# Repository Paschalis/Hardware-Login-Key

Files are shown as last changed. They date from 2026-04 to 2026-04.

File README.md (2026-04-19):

# 🔐 Hardware Login Key

<p align="center">
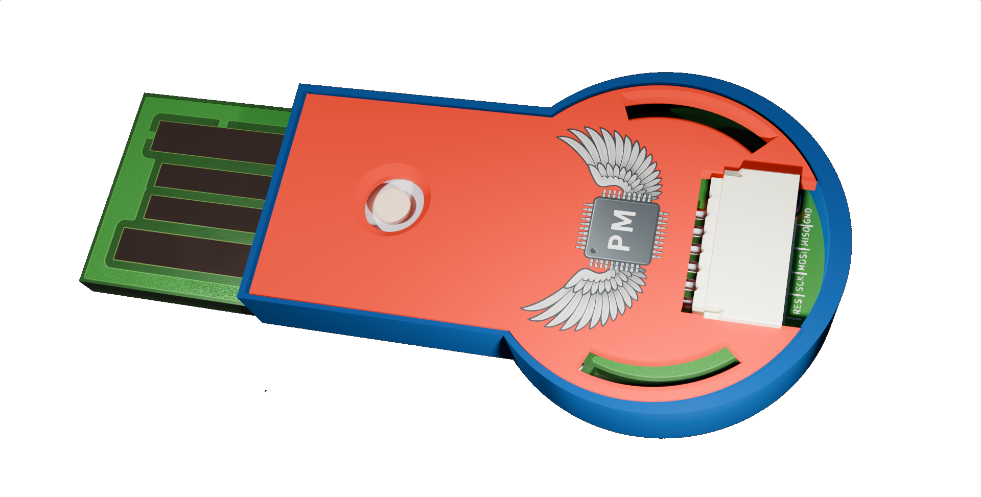
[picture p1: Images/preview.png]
Hardware Login Key preview
  <br/>

  
  
  
  
  
  
</p>

<p align="center">
  <b>Press or tap to auto-type your password suffix — the full password never exists in one place.</b><br/>
  <sub><i>The prefix stays in your mind, the suffix lives in your hand.</i></sub>
</p>

## Introduction

This project offers a straightforward solution for reducing password exposure when logging into a system or website. By pressing a physical button (or touching a capacitive pad) connected to an ATtiny85 microcontroller, the device automatically types a pre-stored password suffix, completing the login without exposing the full credential to observers.


<p align="center">
Pressing the tactile switch on the breadboard prototype sends a keystroke that appears in the terminal.
</p>

## 🎯 Purpose

The aim is to provide a practical alternative to manually typing long or complex passwords in environments where shoulder surfing or observation is a risk. The key injects only a suffix. The prefix stays in the user's memory, so physical possession of the device alone is not enough to authenticate.

## Benefits

- **Reduced exposure** — the full password is never typed in one place or stored in one location
- **Convenience** — complex suffixes are entered automatically with a button press
- **Privacy** — reduces shoulder surfing risk in public or shared environments
- **Portability** — a USB key fits on a keyring and works on any host

## ⚠️ Security Model & Limitations

This device is a **convenience tool**, not a cryptographic security device.

**What it protects against:** shoulder surfing and partial credential capture.

**What it does NOT protect against:**
- **Flash extraction** — the suffix is stored as **plaintext** in ATtiny85 flash
  memory. An attacker with physical access and a standard programmer can dump it
  in under a minute with AVRDUDE. There is no encryption, no secure boot, and no
  hardware protection on the ATtiny85.
- **Compromised host** — keystroke injection via USB HID is visible to any
  software-level keylogger running on the host.

> [!WARNING]
> The ATtiny85 has no hardware security primitives. This device is appropriate for personal, low-threat scenarios. For threat models involving physical access by a motivated attacker, a device with secure boot and encrypted storage is required.
>
>See [SECURITY.md](SECURITY.md) for the full threat model.

## How it Works
The hardware key utilizes an ATtiny85 microcontroller with the V-USB library to implement USB Human Interface Device (HID) keyboard functionality. This allows the ATtiny85 to act as a keyboard when connected to a computer via USB. When the button connected to the ATtiny85 is triggered, it injects a pre-stored password suffix followed by Enter.

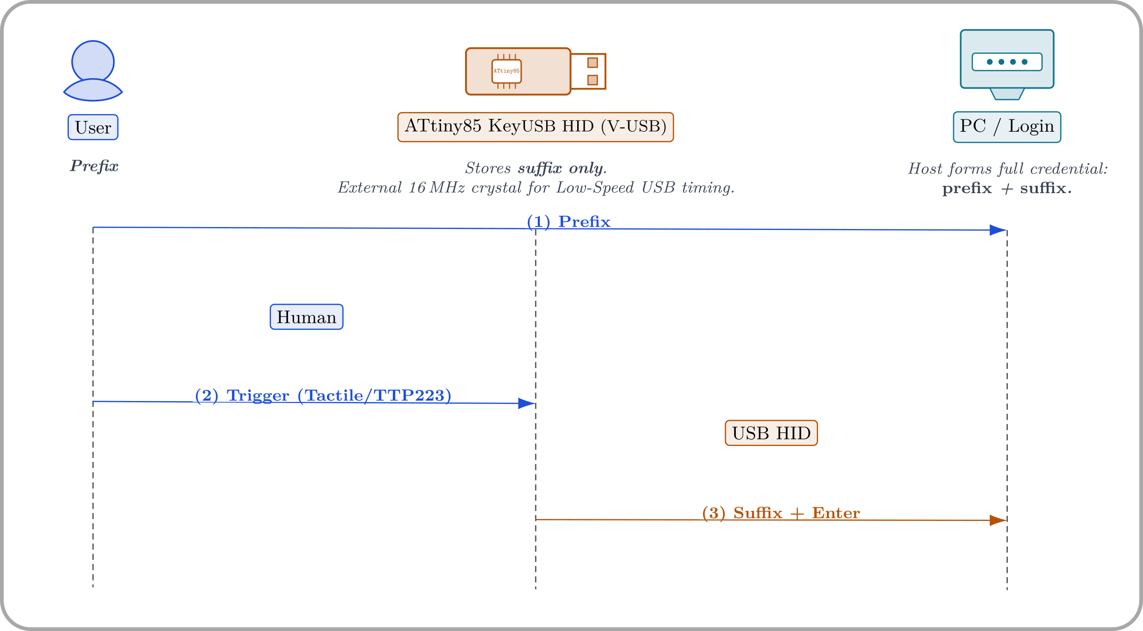
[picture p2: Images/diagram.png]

<p align="center">
Sequence: (1) user types the prefix, (2) user triggers the device (tactile button or
TTP223), and (3) the ATtiny85 injects suffix + Enter via USB HID. The host concatenates the
parts to form the full credential.
</p>


<p align="center">
From code to reality! The ATtiny85 Hardware Login Key project and its various prototypes. What started as a simple idea is now a fully functional set of secure login devices.
</p>

## Firmware Variants

| Variant | Trigger | Folder |
|---|---|---|
| Tactile switch | Push button on PB1 (active-low, internal pull-up) | `C_implementation/tactile_switch/` |
| Touch pad | TTP223 capacitive sensor on PB1 (active-high) | `C_implementation/touch_pad/` |

Both variants share the same V-USB HID keyboard implementation and the same two-piece password concept.

## Compilation Instructions

> [!TIP]
> **First time working with the ATtiny85?**
> 
> Before diving into this project, it's highly recommended to test your hardware setup and compilation process with a simpler program. The **[ATtiny85_Simple_Code_Test](ATtiny85_Simple_Code_Test/README.md)** project is a perfect "Hello, World!" for your hardware. It plays music through a speaker and confirms that your ATtiny85, programmer, and toolchain are all working correctly before you tackle the more complex V-USB library.

You can modify the permissions of `/dev/ttyACM0` to facilitate communication with your serial device. For detailed instructions, [click here](modify_permissions.md).

> [!IMPORTANT]
> **One-Time Fuse Setup for External Crystal**
> 
> The ATtiny85 must be configured to use the external 16MHz crystal. This is done by setting its "fuse bits." This is a **one-time operation** for each chip. Run this once on each fresh chip.
> 
> 1.  Connect your programmer to the ATtiny85.
> 2.  Run the following command to set the fuses for a 16MHz external crystal:
>     ```bash
>     avrdude -c avrisp -p attiny85 -P /dev/ttyACM0 -b 19200 -U lfuse:w:0xFF:m -U hfuse:w:0xDD:m
>     ```
>
> `lfuse 0xFF` selects the external crystal (8–16 MHz, full swing, maximum startup delay). `hfuse 0xDD` enables SPI programming, keeps the RESET pin active, and enables the Brown-Out Detector at 2.7 V — which prevents the chip from executing with an unstable supply during USB plug/unplug events.
>
> ### How to Revert to the Internal Oscillator
> If you later wish to use this ATtiny85 for a different project that does not require an external crystal, you can revert it to use its internal 8MHz oscillator.
> 
> To revert to the internal 8 MHz oscillator (no crystal needed), run the following command:
> ```bash
> avrdude -c avrisp -p attiny85 -P /dev/ttyACM0 -b 19200 -U lfuse:w:0xE2:m -U hfuse:w:0xDF:m
> ```
> This restores the chip to use its internal 8MHz clock source, which is a common setting for many projects (like the `ATtiny85_Simple_Code_Test`).
>
 
> [!WARNING]
> Be extremely careful when setting fuses. Incorrect fuse values can prevent the chip from being reprogrammed via ISP. Always verify values before running the command. Use https://www.engbedded.com/fusecalc/ to double-check.

Install the toolchain:

```bash
# Linux
sudo apt-get install make gcc-avr binutils-avr avr-libc avrdude

# macOS
brew tap osx-cross/avr && brew install avr-gcc avrdude
```

Build and flash (from inside a variant folder):

```bash
cd C_implementation/tactile_switch    # or touch_pad
make          # compile
make upload   # flash via Arduino-as-ISP
```

For detailed programmer wiring, port configuration, and manual build reference, see [INSTRUCTIONS_C.md](INSTRUCTIONS_C.md) and [C_Makefile_Instructions.md](C_Makefile_Instructions.md).

## 📋 Usage — Two-Piece Password

This hardware key uses a **"Two-Piece Password"** approach for enhanced security. The device does not store your full password. Instead, it stores only the complex second half, while you remember and type the simpler first half. This makes the physical key useless if it is ever lost or stolen.

> [!IMPORTANT]
> The device stores only the complex **suffix** of a password. The simpler **prefix** lives in the user's memory. The full credential never exists in a single place.

### The Concept in Action

Let's imagine your full, desired password is: `Key_!#2025_complex`

*   **The part you remember and type first (The Prefix):** `Key_`
*   **The part stored on your hardware key (The Suffix):** `!#2025_complex`

### Login Steps

1.  Navigate to the password field of the login form.
2.  Manually type the first part of your password (e.g., `Key_`).
3.  Plug in your hardware key.
4.  Press the button on the key.
5.  The key will automatically type the complex second half of the password (`!#2025_complex`) and press Enter, logging you in securely.

---

## PCB Designs

### In KiCad
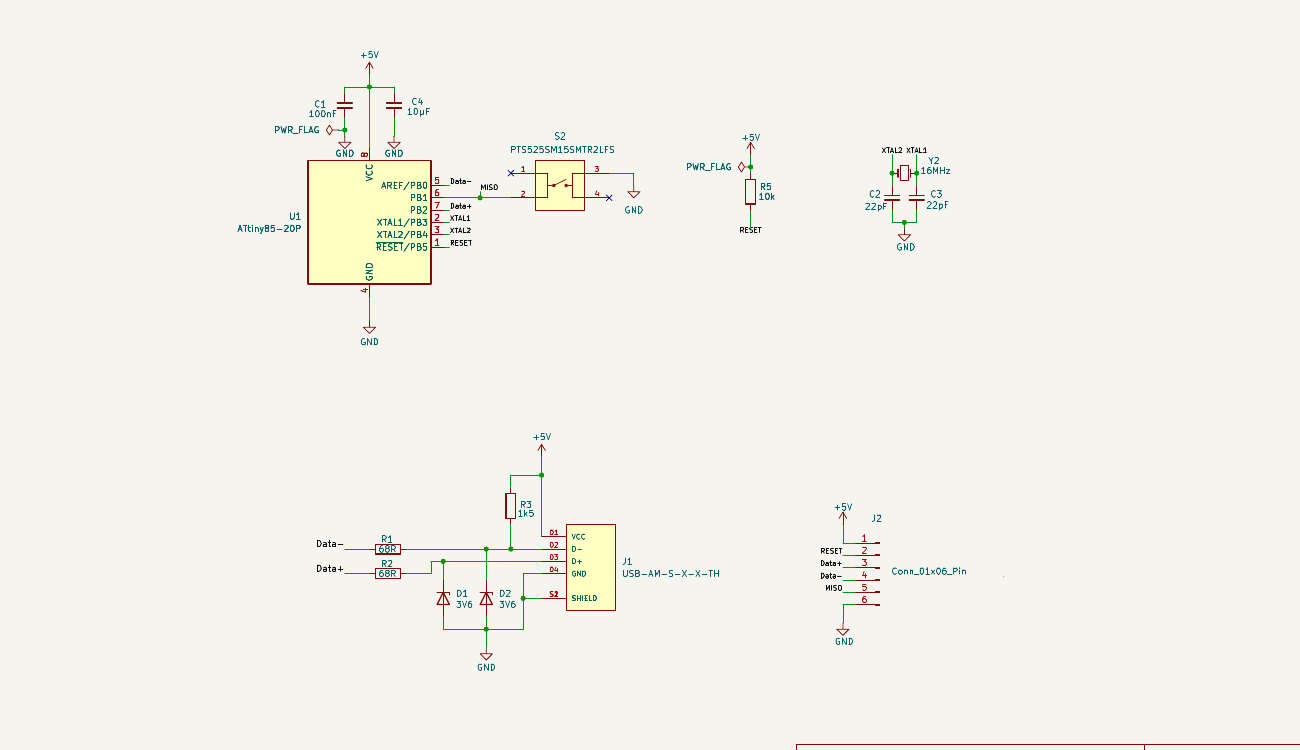
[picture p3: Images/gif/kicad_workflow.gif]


The hardware key is available in multiple PCB package versions to accommodate different assembly preferences:
- **Through-Hole (DIP)**: Easy to hand-solder, ideal for prototyping.
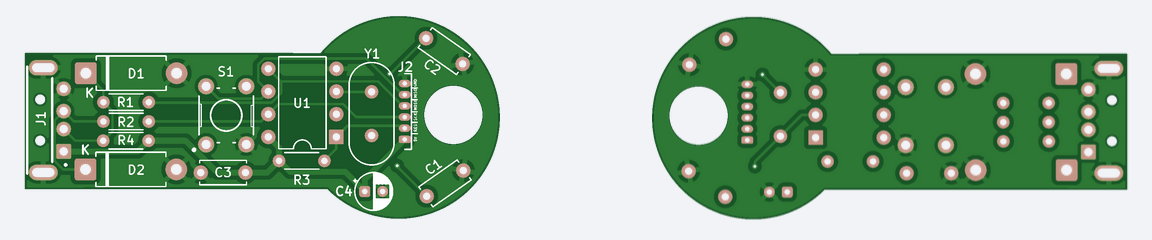
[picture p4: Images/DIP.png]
  - 
  *With tactile switch.*
- **SMD (SOIC)**: Compact and solderable by hand with a fine-tip iron.
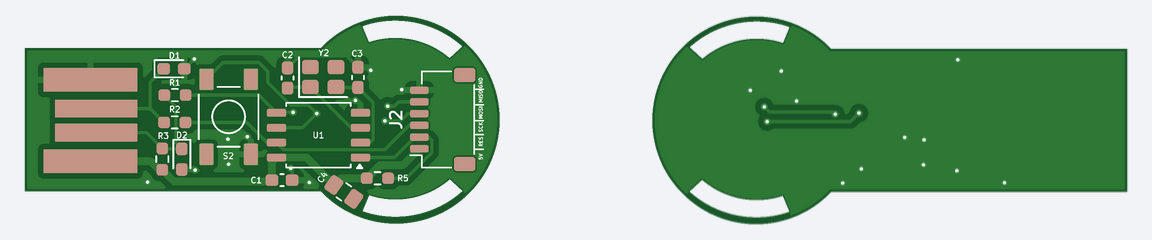
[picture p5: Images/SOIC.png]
SMD SOIC PCB
  - 
  *With tactile switch.*
- **SMD (QFN)**: Smallest footprint with push button.
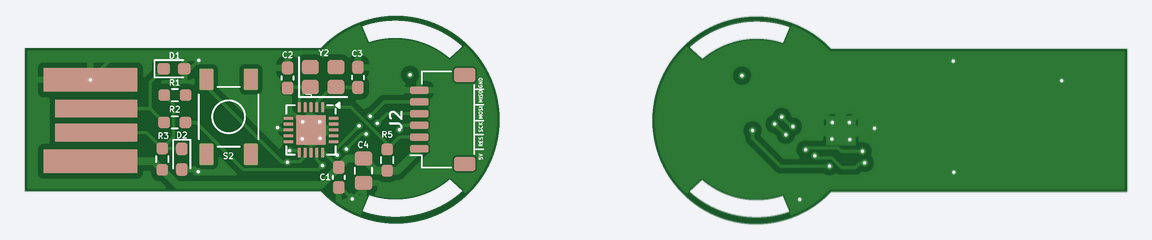
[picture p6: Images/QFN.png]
  - 
    *With tactile switch.*

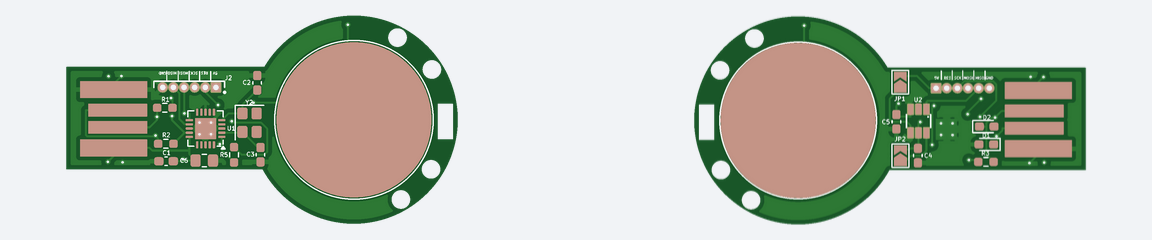
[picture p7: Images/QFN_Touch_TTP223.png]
  - 
    **QFN PCB designed for a touch pad using the TTP223 IC for enhanced reliability.**  
    - Uses a simple high/low output for touch detection, similar to a tactile switch, providing a straightforward 0 or 1 output.  
    - The PCB is designed with **4 layers** to optimize signal integrity and reliability.

## 🛒 Requirements

### Through-Hole (DIP)

| Reference | Value | Footprint | Qty |
|---|---|---|---|
| C1, C2 | 22 pF | C_Disc_D5.0mm_W2.5mm_P5.00mm | 2 |
| C3 | 100 nF | C_Disc_D5.0mm_W2.5mm_P5.00mm | 1 |
| C4 | 10 µF | CP_Radial_D4.0mm_P2.00mm | 1 |
| D1, D2 | 3V6 Zener | D_DO-15_P10.16mm_Horizontal | 2 |
| J1 | USB-AM-S-X-X-TH | SAMTEC_USB-AM-S-X-X-TH | 1 |
| J2 | Conn 1×06 | Molex_PicoBlade_53047-0610 | 1 |
| R1, R2 | 68 Ω | R_Axial_DIN0204_P5.08mm | 2 |
| R3 | 10 kΩ | R_Axial_DIN0204_P5.08mm | 1 |
| R4 | 1.5 kΩ | R_Axial_DIN0204_P5.08mm | 1 |
| S1 | B3F-1000 | SW_B3F-1000 | 1 |
| U1 | ATtiny85-20P | DIP-8_W7.62mm | 1 |
| Y1 | 16 MHz | Crystal_HC49-4H_Vertical | 1 |

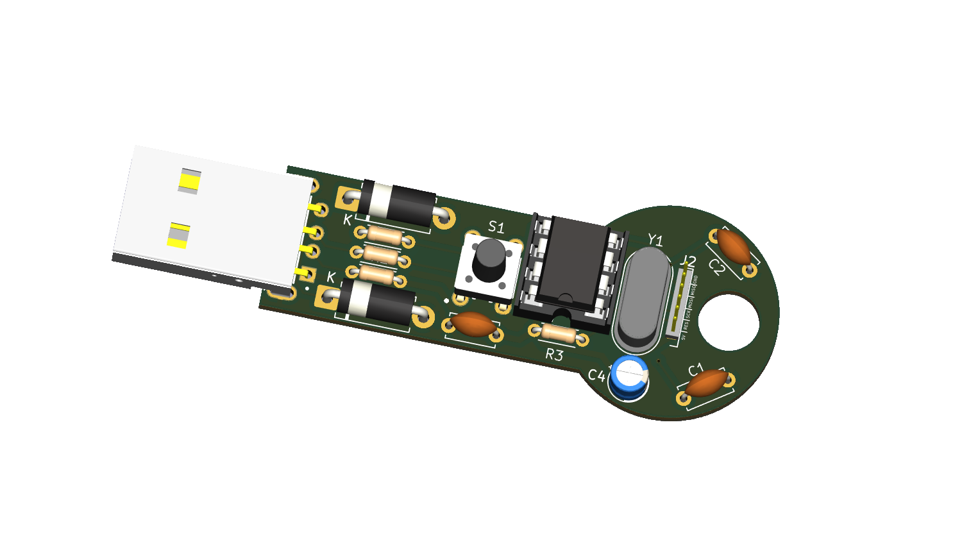
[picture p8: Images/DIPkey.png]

<p align="center">
  <b>DIP 3D render of the hardware login key’s PCB using the Through-Hole (DIP) package in KiCad</b>
</p>

### SMD — SOIC-8

| Reference | Value | Footprint | Qty |
|---|---|---|---|
| C1 | 100 nF | C_0603_HandSolder | 1 |
| C2, C3 | 22 pF | C_0603_HandSolder | 2 |
| C4 | 10 µF | C_0805_HandSolder | 1 |
| D1, D2 | 3V6 Zener | D_0603_HandSolder | 2 |
| J1 | USB-AM-S-X-X-TH | USB_PCB | 1 |
| J2 | Conn 1×06 | JST_SH_SM06B-SRSS-TB | 1 |
| R1, R2 | 68 Ω | R_0603_HandSolder | 2 |
| R3 | 1.5 kΩ | R_0603_HandSolder | 1 |
| R5 | 10 kΩ | R_0603_HandSolder | 1 |
| S2 | PTS525SM15SMTR2LFS | SW_PTS525SM15SMTR2LFS | 1 |
| U1 | ATtiny85-20P | SOIC-8_5.3x5.3mm | 1 |
| Y2 | 16 MHz | Crystal_SMD_3225-4Pin | 1 |

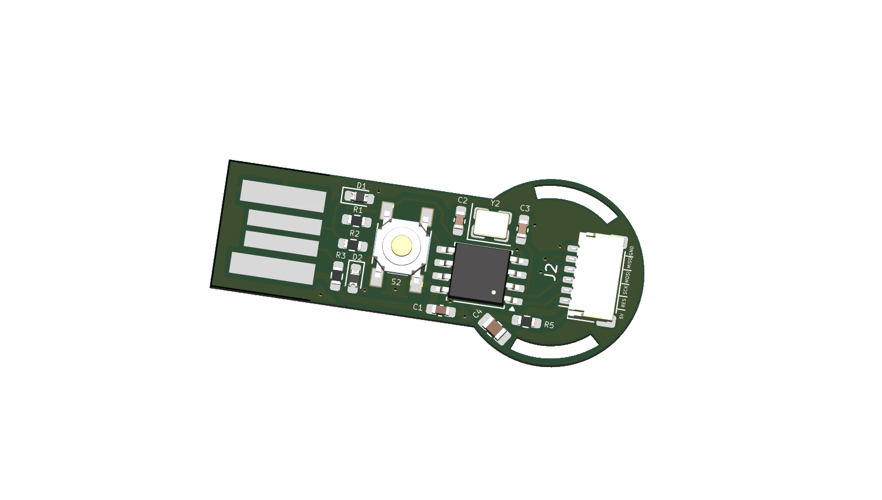
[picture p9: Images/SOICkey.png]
SMD SOIC PCB

<p align="center">
  <b>3D model of the hardware login key’s PCB using the SMD (SOIC) package in KiCad.</b>
</p>

### SMD — QFN-20 with tactile switch

| Reference | Value | Footprint | Qty |
|---|---|---|---|
| C1 | 100 nF | C_0603_HandSolder | 1 |
| C2, C3 | 22 pF | C_0603_HandSolder | 2 |
| C4 | 10 µF | C_0805_HandSolder | 1 |
| D1, D2 | 3V6 Zener | D_0603_HandSolder | 2 |
| J1 | USB-AM-S-X-X-TH | USB_PCB | 1 |
| J2 | Conn 1×06 | JST_SH_SM06B-SRSS-TB | 1 |
| R1, R2 | 68 Ω | R_0603_HandSolder | 2 |
| R3 | 1.5 kΩ | R_0603_HandSolder | 1 |
| R5 | 10 kΩ | R_0603_HandSolder | 1 |
| S2 | PTS525SM15SMTR2LFS | SW_PTS525SM15SMTR2LFS | 1 |
| U1 | ATtiny85-20M | QFN-20-1EP_4x4mm | 1 |
| Y2 | 16 MHz | Crystal_SMD_3225-4Pin | 1 |

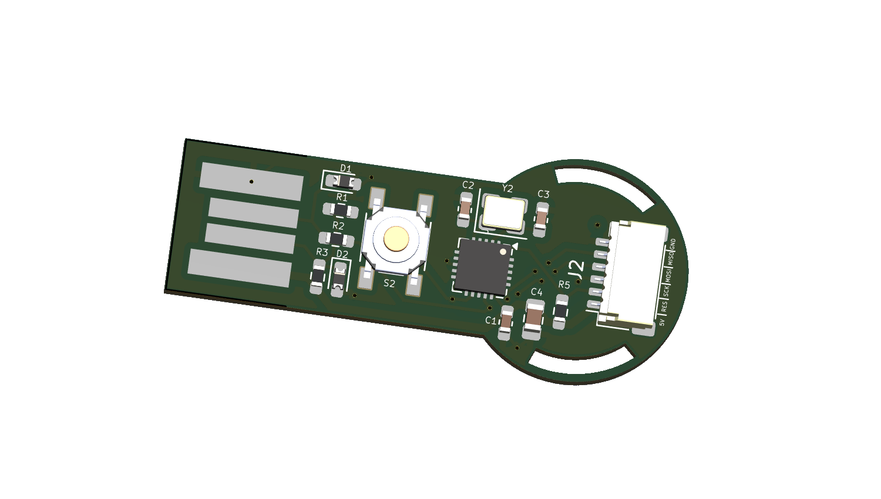
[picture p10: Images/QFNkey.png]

<p align="center">
  <b>3D model of the hardware login key’s PCB using the QFN package in KiCad.</b>
</p>

### SMD — QFN-20 with TTP223 capacitive touch (4-layer PCB) and Reversible USB Functionality

| Reference | Value | Footprint | Qty |
|---|---|---|---|
| C1 | 100 nF | C_0603_HandSolder | 1 |
| C2, C3 | 22 pF | C_0603_HandSolder | 2 |
| C4 | 1 µF | C_0603_HandSolder | 1 |
| C5 | 30 pF | C_0603_HandSolder | 1 |
| C6 | 10 µF | C_0805_HandSolder | 1 |
| D1, D2 | 3V6 Zener | D_0603_HandSolder | 2 |
| J1 | USB-AM-S-X-X-TH | USB_PCB | 1 |
| J2 | M50-3930642 | HARWIN_M50-3930642 | 1 |
| R1, R2 | 68 Ω | R_0603_HandSolder | 2 |
| R3 | 1.5 kΩ | R_0603_HandSolder | 1 |
| R5 | 10 kΩ | R_0603_HandSolder | 1 |
| TP1, TP2 | Test point | TestPoint_Pad_D3.0mm | 2 |
| U1 | ATtiny85-20M | QFN-20-1EP_4x4mm | 1 |
| U2 | TTP223-BA6 | SOT23-6 | 1 |
| Y2 | 16 MHz | Crystal_SMD_3225-4Pin | 1 |

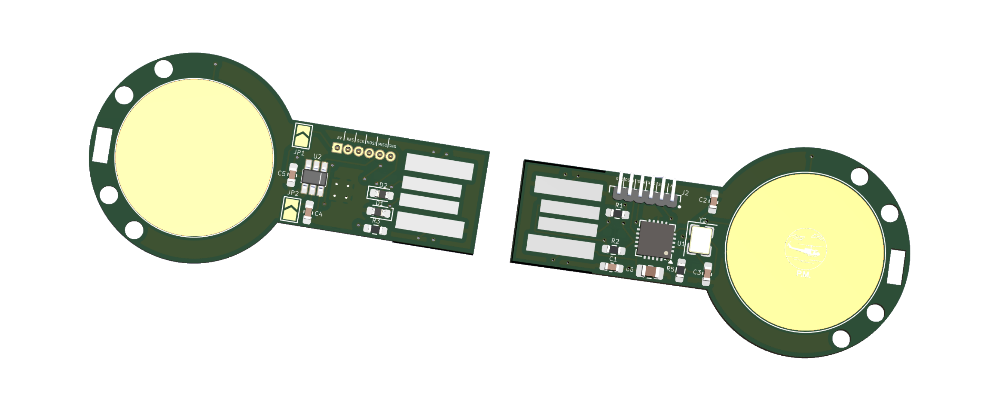
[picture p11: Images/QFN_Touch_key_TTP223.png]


<p align="center">
  <b>3D model of the hardware login key’s PCB using the QFN package in KiCad.</b> 
  <br> 
  With the TTP223 IC. (Uses simple high/low output for touch detection, similar to a tactile switch, with default code for straightforward 0 or 1 output.)
</p>

## 🏗️ 3D Printed Enclosure

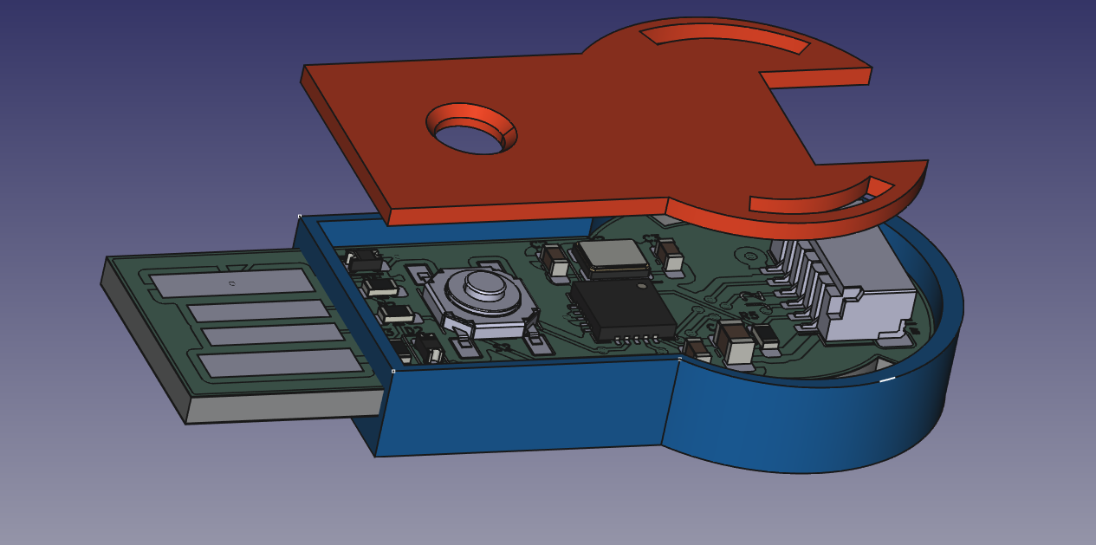
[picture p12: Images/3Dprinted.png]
Enclosure


A 3D printed case is available for the hardware key. To use it, follow these steps:
1. Open the `3d_printed_case` folder.
2. Load the `hardware_key_case.stl` file into your 3D printer software.
3. Print the case using your 3D printer.
4. Once printed, assemble the hardware key inside the case for added protection and aesthetics.

## 📄 System Requirements Specification

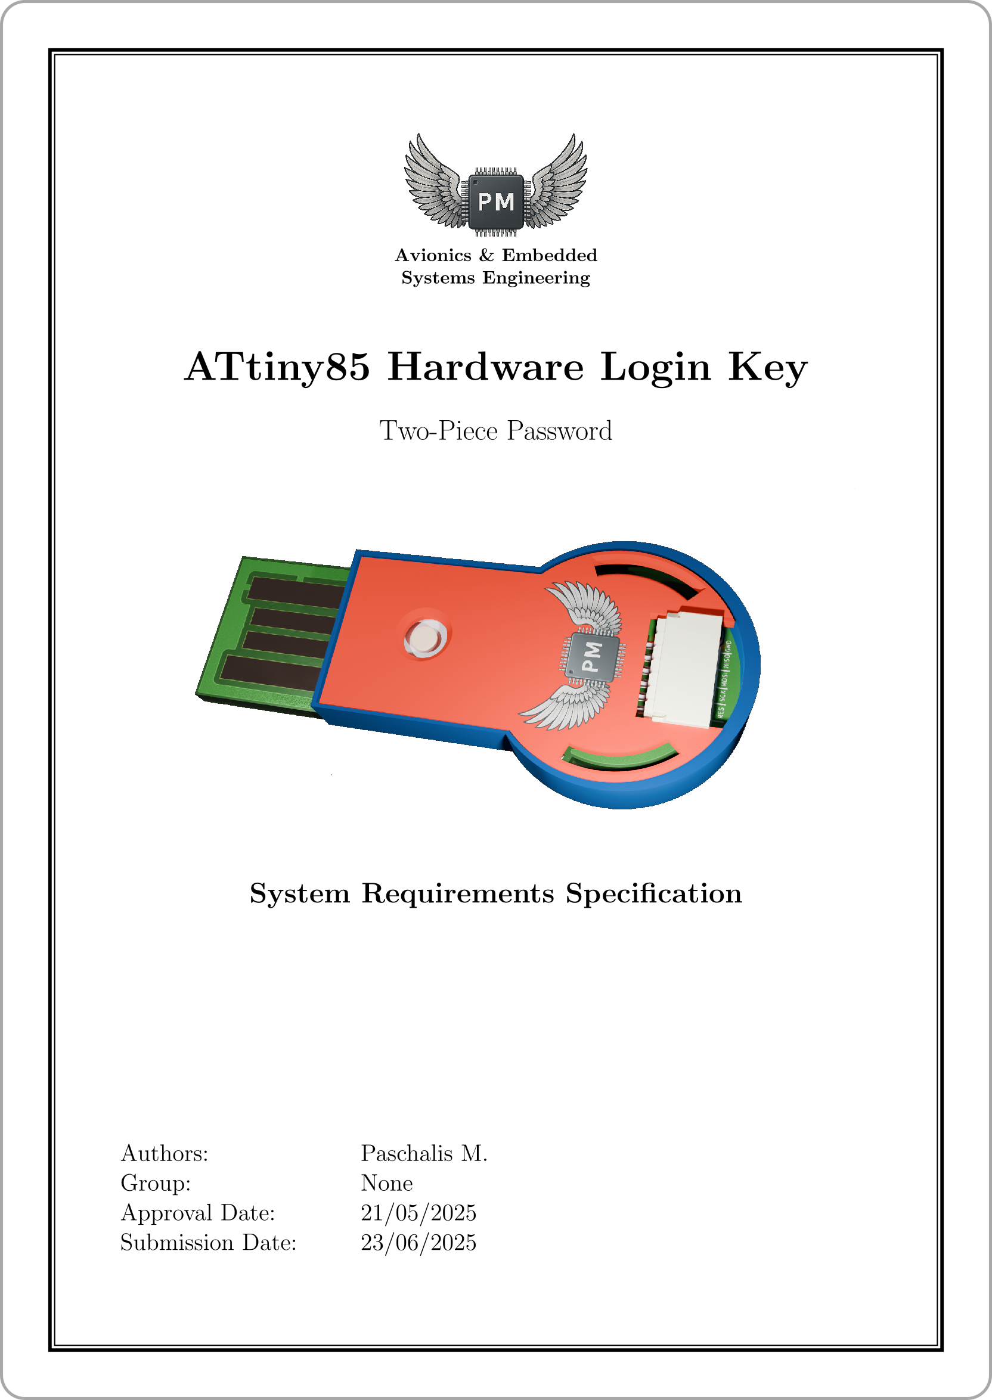
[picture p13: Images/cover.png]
SRS Cover

<p align="center">
  <b>Click the image to open the full SRS (PDF).</b>
</p>

## 🧑‍💻 Authors
-  

## 👥 Contributors
-
-
-
-

## 🙏 Acknowledgements

This project stands on the shoulders of giants. A special thank you to the developers and communities behind these essential open-source tools:

*   **V-USB:** The core USB functionality of this hardware key is made possible by the V-USB library, a firmware-only USB driver for AVR microcontrollers from [Objective Development](https://www.obdev.at/vusb/).
*   **KiCad:** All PCB designs were created using KiCad, a powerful, free, and open-source electronics design automation (EDA) suite. Learn more at the [KiCad website](https://www.kicad.org/).

## 📜 License

This project is licensed under the [GPLv3 License](https://opensource.org/licenses/GPL-3.0) - see the [LICENSE](LICENSE) file for details.

- <a href="LICENSE">
  
</a>

**Thank you for visiting Hardware-Login-Key!** 🔐✨

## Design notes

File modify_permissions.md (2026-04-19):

# Modifying Permissions for `/dev/ttyACM0`

When working with serial devices like `/dev/ttyACM0` on a Linux system, you might need to modify the permissions to allow read and write access for all users. This can be useful when interacting with devices such as microcontrollers, modems, or other serial communication devices. The `chmod` command can be used for this purpose.

## Step-by-Step Guide

1. **Open a Terminal**: Access your terminal on the Linux system.

2. **Execute the `chmod` Command**:
   To modify the permissions of `/dev/ttyACM0` to allow read and write access for all users, use the following command:

   ```sh
   sudo chmod a+rw /dev/ttyACM0
   ```
Here’s a breakdown of the command:

- sudo: Executes the command with superuser privileges.
- chmod: Stands for "change mode", which is used to change file or directory permissions.
- a+rw: Grants read (r) and write (w) permissions to all users (a stands for all).
- /dev/ttyACM0: Specifies the device file for which the permissions are being modified.

3. **Verify the Permissions**:
    You can verify the permissions of the device file using the ls command:

    ```sh
    ls -l /dev/ttyACM0
    ```

    The output should show that all users have read and write permissions, indicated by crw-rw-rw- in the permission string.

## Example Output

After executing the chmod command, running ls -l /dev/ttyACM0 should produce output similar to this:

```bash
crw-rw-rw- 1 root dialout 166, 0 Jul  7 12:34 /dev/ttyACM0
```
[⬅ Back to README](README.md)

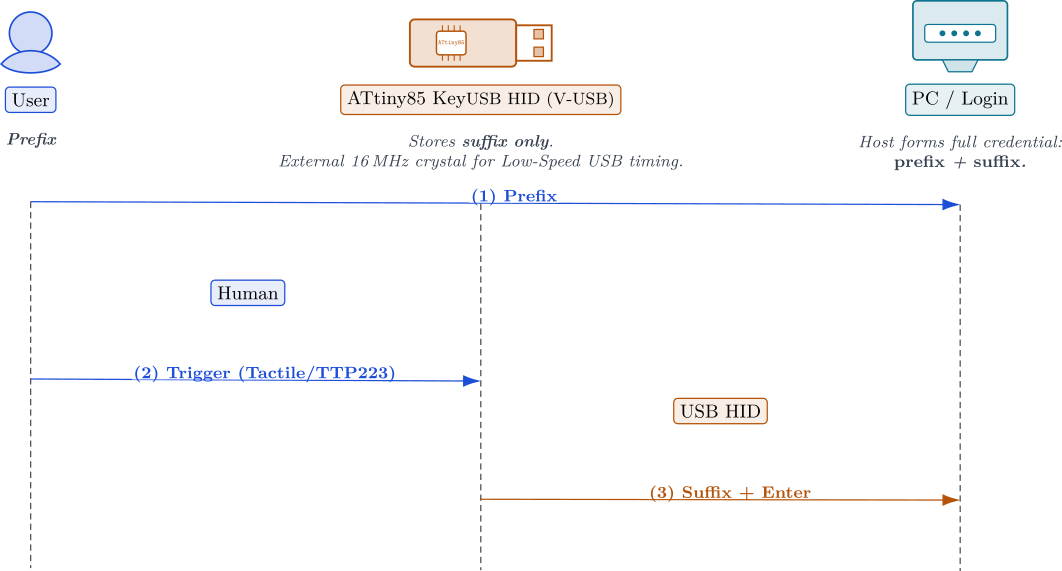
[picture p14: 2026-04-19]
Images/diagram1.png

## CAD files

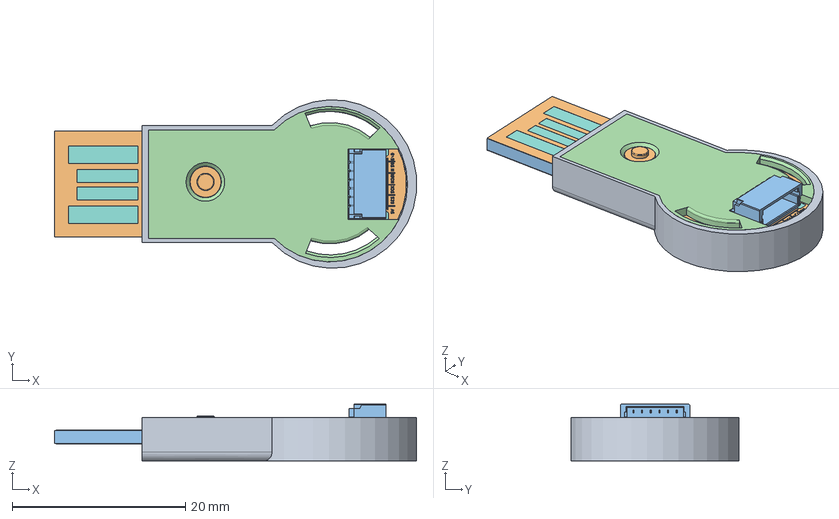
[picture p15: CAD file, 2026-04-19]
3d_printed_case/enclosure.FCStd
41.7 x 19.4 x 6.54 mm
D_0603_1608Metric
SM06B-SRSS-TB(LF)(SN)--3DModel-STEP-269445
D_0603_1608Metric001
C_0603_1608Metric
C_0603_1608Metric001
QFN-20-1EP_4x4mm_P0.5mm_EP2.5x2.5mm
R_0603_1608Metric
C_0603_1608Metric002
PTS525SM15SMTR2LFS
Crystal_SMD_3225-4Pin_3.2x2.5mm
R_0603_1608Metric001
R_0603_1608Metric002
C_0805_2012Metric
R_0603_1608Metric003
QFN_copper
QFN_silkscreen
QFN_soldermask
QFN_PCB

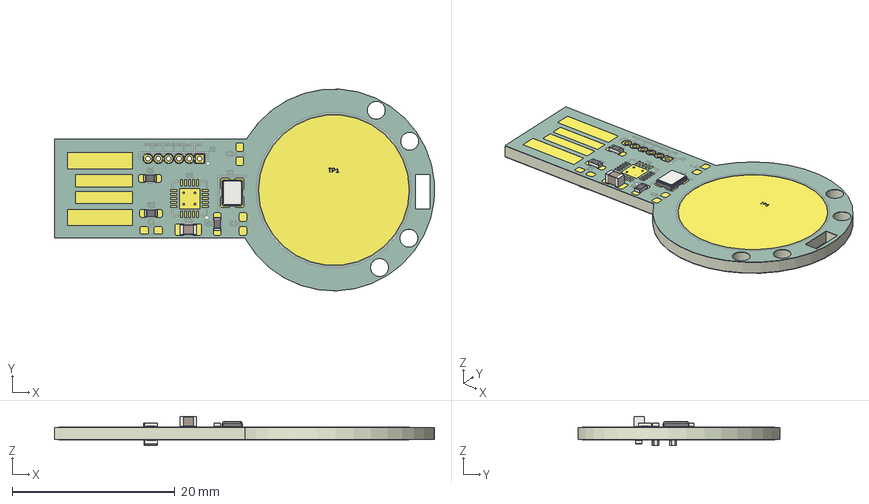
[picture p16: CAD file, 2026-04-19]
PCB_Designs/SMD_QFN_Touch_TTP223/.step
46.6 x 24.8 x 3.59 mm
R_0603_1608Metric x 4
C_0805_2012Metric
Crystal_SMD_3225-4Pin_3.2x2.5mm
D_0603_1608Metric x 2
QFN_Touch_TTP223_copper
QFN_Touch_TTP223_silkscreen x 2
QFN_Touch_TTP223_soldermask x 2
QFN_Touch_TTP223_PCB

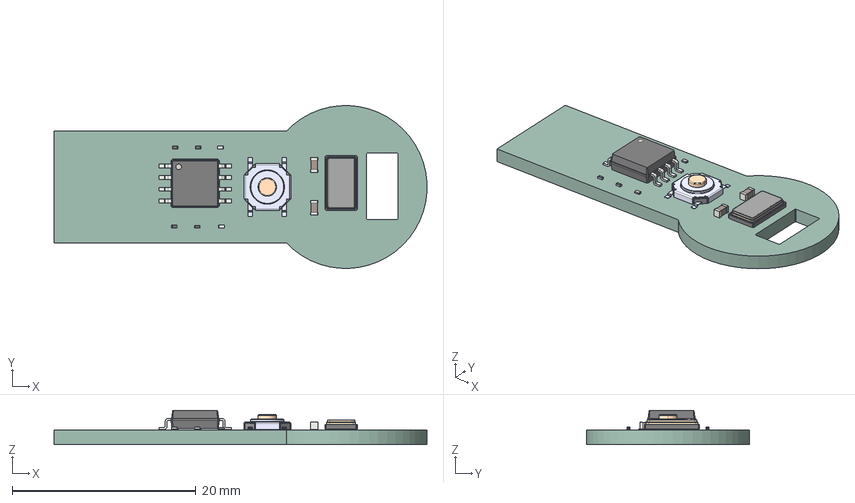
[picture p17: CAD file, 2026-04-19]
PCB_Designs/SMD_SOIC/SOIC.step
40.6 x 17.7 x 3.71 mm
C_0603_1608Metric x 2
SOIC_8_5275x5275mm_P127mm
R_0201_0603Metric x 4
PTS525SM15SMTR2 LFS
SMD_0603_4Pin
LED_0201_0603Metric x 2
SOIC_PCB

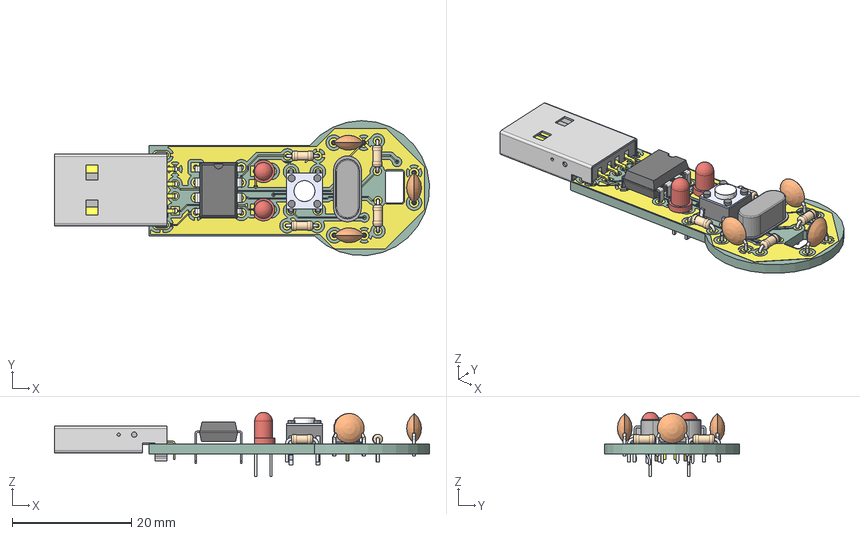
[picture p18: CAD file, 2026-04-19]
PCB_Designs/Through-Hole_DIP/KicadHardwareKey.step
62.8 x 22.6 x 10.8 mm
C_Disc_D50mm_W25mm_P500mm x 3
R_Axial_DIN0204_L36mm_D16mm_P508mm_Horizontal x 4
Crystal_HC49-4H_Vertical
USB-AM-S-F-B-TH
LED_D3.0mm x 2
DIP-8_W7.62mm
B3F-1000
Through-Hole_DIP_track_1
Through-Hole_DIP_track_2
Through-Hole_DIP_track_3
Through-Hole_DIP_track_4
Through-Hole_DIP_track_5
Through-Hole_DIP_track_6
Through-Hole_DIP_track_7
Through-Hole_DIP_track_8
Through-Hole_DIP_track_9
Through-Hole_DIP_track_10
Through-Hole_DIP_track_11
Through-Hole_DIP_track_12
Through-Hole_DIP_track_13
Through-Hole_DIP_track_14
Through-Hole_DIP_track_15
Through-Hole_DIP_track_16
Through-Hole_DIP_track_17
Through-Hole_DIP_track_18
Through-Hole_DIP_track_19
Through-Hole_DIP_track_20
Through-Hole_DIP_track_21
Through-Hole_DIP_track_22
Through-Hole_DIP_track_23
Through-Hole_DIP_track_24
Through-Hole_DIP_track_25
Through-Hole_DIP_track_26
Through-Hole_DIP_track_27
Through-Hole_DIP_track_28
Through-Hole_DIP_track_29
Through-Hole_DIP_track_30
Through-Hole_DIP_track_31
Through-Hole_DIP_track_32
Through-Hole_DIP_track_33
Through-Hole_DIP_track_34
Through-Hole_DIP_track_35
Through-Hole_DIP_track_36
Through-Hole_DIP_track_37
Through-Hole_DIP_track_38
Through-Hole_DIP_track_39
Through-Hole_DIP_track_40
Through-Hole_DIP_track_41
Through-Hole_DIP_track_42
Through-Hole_DIP_track_43
Through-Hole_DIP_track_44
Through-Hole_DIP_track_45
Through-Hole_DIP_track_46
Through-Hole_DIP_track_47
Through-Hole_DIP_track_48
Through-Hole_DIP_track_49
Through-Hole_DIP_track_50
Through-Hole_DIP_track_51
Through-Hole_DIP_track_52
Through-Hole_DIP_track_53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

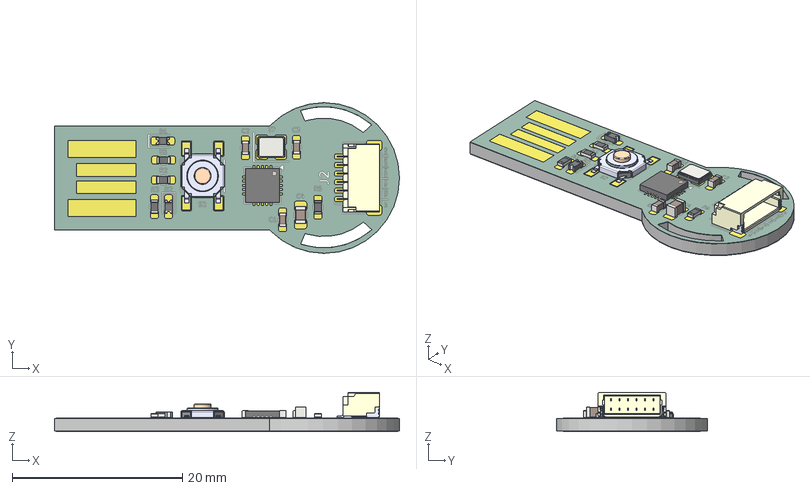
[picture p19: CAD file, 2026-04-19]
3d_printed_case/SOIC.step
40.6 x 17.7 x 4.60 mm
D_0603_1608Metric x 2
SM06B-SRSS-TB(LF)(SN)--3DModel-STEP-269445
C_0603_1608Metric x 3
QFN-20-1EP_4x4mm_P0.5mm_EP2.5x2.5mm
R_0603_1608Metric x 4
PTS525SM15SMTR2LFS
Crystal_SMD_3225-4Pin_3.2x2.5mm
C_0805_2012Metric
QFN_copper
QFN_silkscreen
QFN_soldermask
QFN_PCB

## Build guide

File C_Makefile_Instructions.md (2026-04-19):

# Using the Makefile

Each firmware variant (`tactile_switch`, `touch_pad`) ships with its own
Makefile. All commands below must be run from inside the variant folder.

## Quick reference

| Command | What it does |
|---|---|
| `make` | Compile firmware → `main.elf` + `main.hex` |
| `make upload` | Flash `main.hex` to the ATtiny85 via Arduino-as-ISP |
| `make set-fuses` | Configure fuse bits for 16 MHz external crystal (one-time per chip) |
| `make clean` | Delete build artefacts (`*.elf`, `*.hex`) |

## Makefile variables you may need to change

Open the Makefile in your editor and adjust these at the top if needed:

```makefile
PROGRAMMER = avrisp          # programmer type (avrisp2, usbtiny, …)
PORT       = /dev/ttyACM0   # serial port (COMx on Windows, /dev/cu.* on macOS)
BAUD       = 19200           # must match ArduinoISP sketch
```

## Typical workflow

```bash
# First time only — set fuses on a fresh chip
cd C_implementation/tactile_switch
make set-fuses

# Every time you change the firmware
make
make upload
```

## Prerequisites

```bash
# Debian / Ubuntu
sudo apt-get install make gcc-avr binutils-avr avr-libc avrdude

# macOS
brew tap osx-cross/avr && brew install avr-gcc avrdude
```

[⬅ Back to README](README.md)

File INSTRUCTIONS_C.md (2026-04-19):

# Programming the ATtiny85 — C Implementation

This project uses a **Makefile** for all build and flash operations. Manual
`avr-gcc` invocations are shown for reference only; always use `make` for
a correct, reproducible build.

## Prerequisites

Install the AVR toolchain:

```bash
# Debian / Ubuntu / Raspberry Pi OS
sudo apt-get install make gcc-avr binutils-avr avr-libc avrdude

# macOS (Homebrew)
brew tap osx-cross/avr
brew install avr-gcc avrdude
```

## Firmware variants

| Folder | Trigger | Notes |
|---|---|---|
| `C_implementation/tactile_switch/` | Tactile push button on PB1 | Active-low, internal pull-up enabled |
| `C_implementation/touch_pad/` | TTP223 capacitive sensor on PB1 | Active-high, no pull-up |

Navigate to whichever variant you are building before running any `make` command.

## Build with Make (recommended)

```bash
cd C_implementation/tactile_switch   # or touch_pad
make          # compiles main.elf and main.hex
make upload   # flashes to chip via Arduino-as-ISP
make clean    # removes build artefacts
```

To set fuses on a fresh chip (one-time operation per chip):

```bash
make set-fuses
```

## Manual build (for reference only)

A V-USB project requires the V-USB sources and the correct `F_CPU` define.
The bare minimum correct invocation is:

```bash
# From inside C_implementation/tactile_switch (or touch_pad):
avr-gcc -mmcu=attiny85 -DF_CPU=16000000UL -Wall -Os \
  -I./usbdrv \
  -o main.elf \
  main.c \
  usbdrv/usbdrv.c \
  usbdrv/usbdrvasm.S

avr-objcopy -O ihex -R .eeprom main.elf main.hex
```

> [!WARNING]
> A bare `avr-gcc -mmcu=attiny85 -Os -o main.elf main.c` will fail — it is
> missing the V-USB sources, the include path, and the mandatory `-DF_CPU`
> define. Use `make` instead.

## Programmer options

### Option A — Arduino as ISP (used by default in Makefile)

1. **Prepare Arduino Uno**: Upload the ArduinoISP sketch to your Arduino Uno board using the Arduino IDE. This sketch turns the Arduino Uno into an ISP programmer.

2. **Connect Arduino Uno as ISP**: Connect your Arduino Uno to your computer via USB. Then, connect the following pins from the Arduino Uno to the ATtiny85:
    - Arduino Uno **5V** pin to ATtiny85 **VCC** pin
    - Arduino Uno **GND** pin to ATtiny85 **GND** pin
    - Arduino Uno **Pin 10** (SS) to ATtiny85 **RESET** pin
    - Arduino Uno **Pin 11** (MOSI) to ATtiny85 **MOSI** pin
    - Arduino Uno **Pin 12** (MISO) to ATtiny85 **MISO** pin
    - Arduino Uno **Pin 13** (SCK) to ATtiny85 **SCK** pin
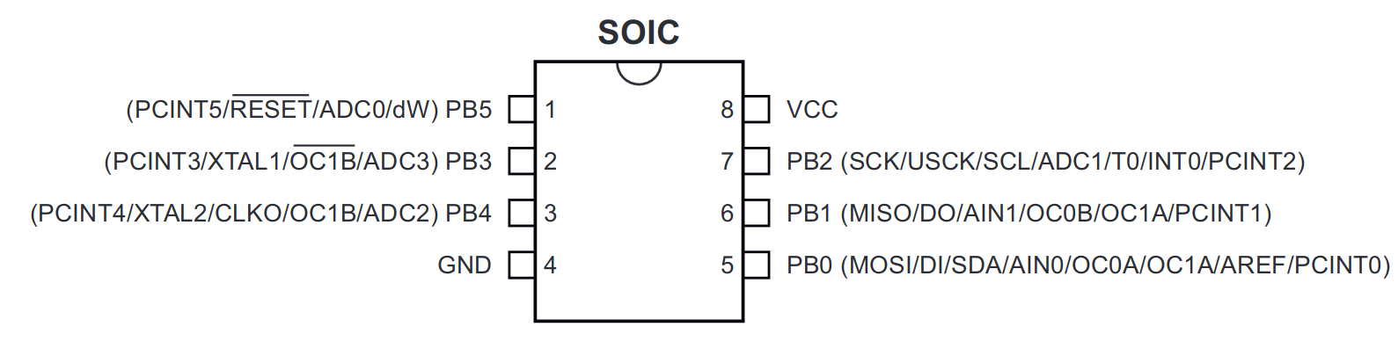
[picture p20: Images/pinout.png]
      
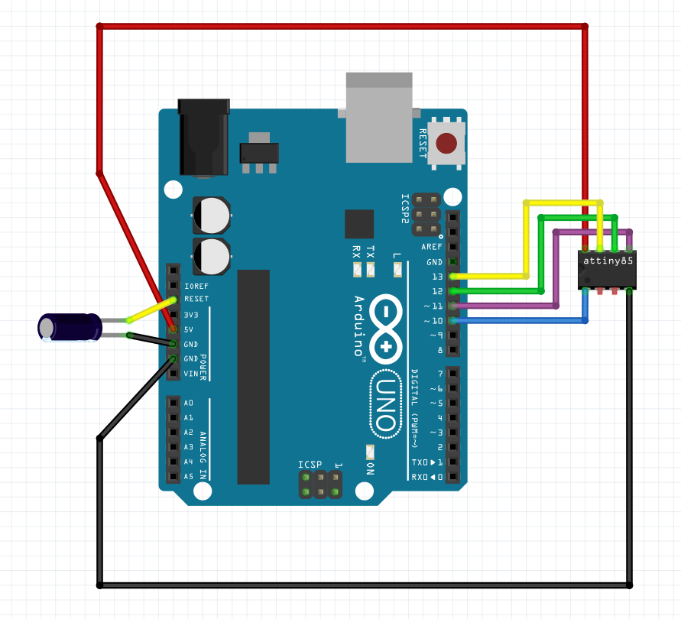
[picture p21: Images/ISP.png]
      

3. **Compile Your Code**: Compile your code into a `.hex` file using `avr-gcc` and `avr-objcopy`. For example:

    ```bash
    avr-gcc -mmcu=attiny85 -DF_CPU=16000000UL -Os -I./usbdrv -o main.elf main.c usbdrv/usbdrv.c usbdrv/usbdrvasm.S
    avr-objcopy -O ihex -R .eeprom main.elf main.hex
    ```

4. **Upload `.hex` File**: Use AVRDUDE or a similar programming tool to upload the `.hex` file to the ATtiny85. For example:

    ```bash
    avrdude -c avrisp -p attiny85 -P <port> -b 19200 -U flash:w:main.hex
    ```    
    Replace `<port>` with the serial port connected to your Arduino Uno.

    for example my port was /dev/ttyACM0
    
    ```bash

    avrdude -c avrisp -p attiny85 -P /dev/ttyACM0 -b 19200 -U flash:w:main.hex
    ```
    Replace `/dev/ttyACM0` with the correct port for your system (`/dev/cu.usbmodem*` on macOS, `COMx` on Windows).

5. **Verify Upload**: After uploading the `.hex` file, verify that the programming was successful. AVRDUDE may provide feedback or confirmation messages.

6. **Reset ATtiny85**: Once the upload is complete, reset the ATtiny85 by power-cycling it or using the RESET pin.

7. **Run Program**: After resetting the ATtiny85, it should execute your program.

### Option B — AVRISP mkII

```bash
avrdude -c avrisp2 -p attiny85 -U flash:w:main.hex
```

### Option C — Micronucleus bootloader

If the chip already has a Micronucleus bootloader flashed:

```bash
micronucleus --run main.hex
```

## Serial port permissions (Linux only)

```bash
sudo chmod a+rw /dev/ttyACM0
# Or add your user to the dialout group permanently:
sudo usermod -aG dialout $USER   # then log out and back in
```

[⬅ Back to README](README.md)

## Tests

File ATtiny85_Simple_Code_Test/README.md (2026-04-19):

# Christmas Song Playlist for ATtiny85

This project contains the code to play a playlist of three Christmas songs on an ATtiny85 microcontroller. It is available in two separate versions: a standard C implementation and an object-oriented C++ implementation.

The playlist includes:
1.  Jingle Bells
2.  We Wish You a Merry Christmas
3.  Deck the Halls

## Project Structure

The repository is organized into two self-contained folders, each representing a complete version of the project:

*   **`C_Version/`**: A straightforward, procedural implementation using C (`.c`, `.h`).
*   **`CPP_Version/`**: An object-oriented implementation using C++ (`.cpp`, `.hpp`), which organizes the code into `Song` and `Speaker` classes.

Each folder contains its own source code and a dedicated `Makefile`.

## Option 1: Using the Makefile (Recommended)

This is the easiest and quickest way to compile and upload the code. The process is the same for both versions.

1.  **Navigate to the desired version's folder.**
    ```bash
    # To use the C++ version
    cd CPP_Version/
    
    # OR
    
    # To use the C version
    cd C_Version/
    ```

2.  **Compile the code.**
    This command builds the project and creates the `.hex` file.
    ```bash
    make
    ```

3.  **Upload to the ATtiny85.**
    This will compile if needed and then upload the program.
    ```bash
    make upload
    ```

4.  **(Optional) Clean up generated files.**
    ```bash
    make clean
    ```

## Option 2: Manual Compilation

If you prefer to run the commands yourself, follow these steps.

### For the C++ Version

1.  **Navigate to the C++ directory:**
    ```bash
    cd CPP_Version/
    ```
2.  **Compile with `avr-g++`:**
    ```bash
    avr-g++ -mmcu=attiny85 -DF_CPU=8000000UL -Os -o Christmas_song.elf Christmas_song.cpp
    ```
3.  **Create the HEX file:**
    ```bash
    avr-objcopy -O ihex -R .eeprom Christmas_song.elf Christmas_song.hex
    ```
4.  **Upload to the ATtiny85:**
    ```bash
    avrdude -c arduino -p attiny85 -P /dev/ttyACM0 -b 19200 -U flash:w:Christmas_song.hex
    ```

### For the C Version

1.  **Navigate to the C directory:**
    ```bash
    cd C_Version/
    ```
2.  **Compile with `avr-gcc`:**
    ```bash
    avr-gcc -mmcu=attiny85 -DF_CPU=8000000UL -Os -o Christmas_song.elf Christmas_song.c
    ```
3.  **Create the HEX file:**
    ```bash
    avr-objcopy -O ihex -R .eeprom Christmas_song.elf Christmas_song.hex
    ```
4.  **Upload to the ATtiny85:**
    ```bash
    avrdude -c arduino -p attiny85 -P /dev/ttyACM0 -b 19200 -U flash:w:Christmas_song.hex
    ```

## Demo

Listen to a recording of the ATtiny85 playing the song playlist:

**[▶️ Listen to the Song Demo](./assets/song_demo.mp3)**

## Requirements
- ATtiny85 microcontroller
- Speaker or Piezo Buzzer (or an LED for visual feedback)
- Arduino Uno (or another AVR programmer)
- Linux environment with `avr-gcc`, `avr-g++`, `avr-objcopy`, and `avrdude` installed

## Notes

> [!IMPORTANT]
> Ensure that the wiring between your programmer (e.g., Arduino Uno) and the ATtiny85 is correct before uploading. Incorrect wiring can prevent programming or damage the chip.
> 
> For more detailed wiring instructions, see the instruction files:
> - **[See the C Instructions](../INSTRUCTIONS_C.md)**
> - **[See the C++ Instructions](../INSTRUCTIONS_CPP.md)**

> [!NOTE]
> The speaker/buzzer should be connected to **PB1** (physical pin 6 on the ATtiny85) and Ground.

> [!TIP]
> If you don't have a speaker, you can connect an LED (with an appropriate current-limiting resistor) to the same pin (PB1). The LED will blink in the rhythm of the songs, which is a great way to debug and confirm that the code is running correctly.

> [!NOTE]
> You may need to adjust the `PORT` variable inside the `Makefile` in each directory to match the port your programmer is connected to on your system.

[⬅️ Go Back to Main README](../README.md)

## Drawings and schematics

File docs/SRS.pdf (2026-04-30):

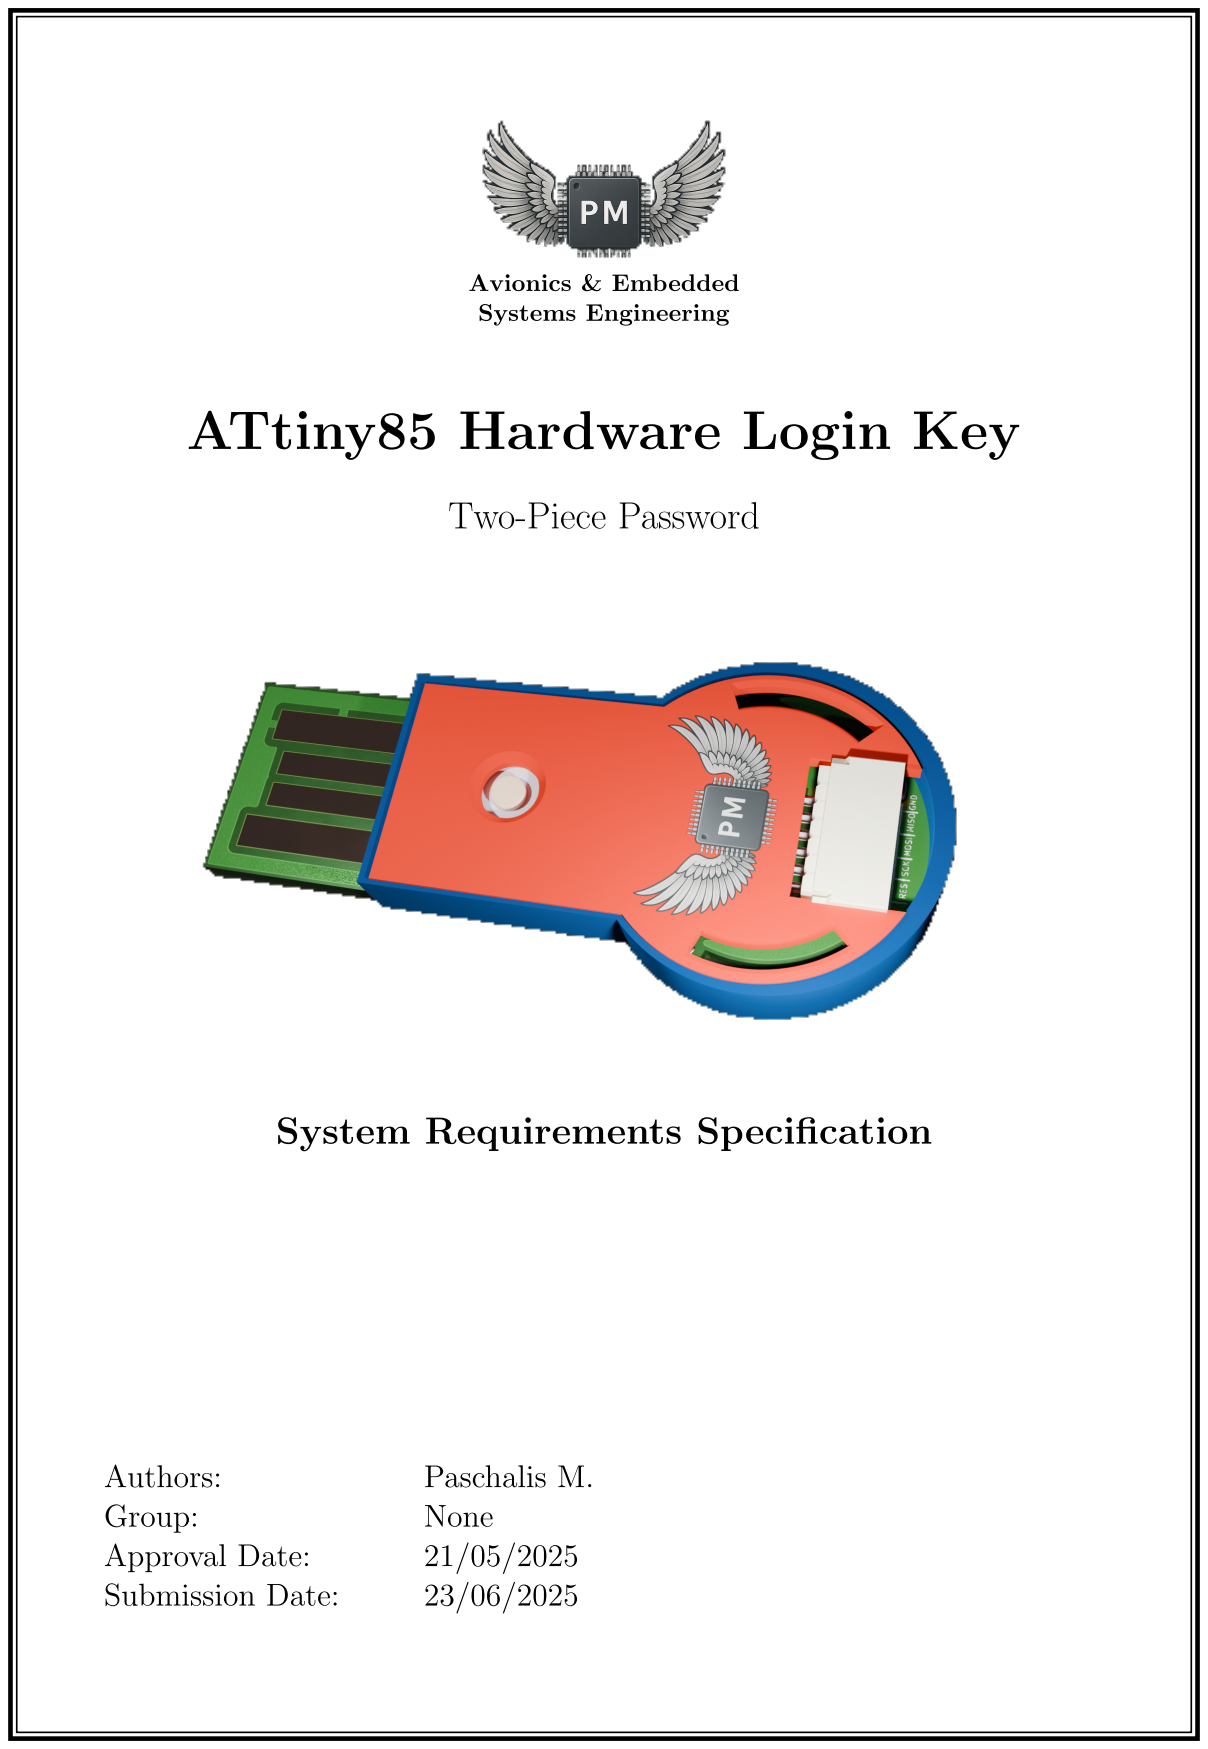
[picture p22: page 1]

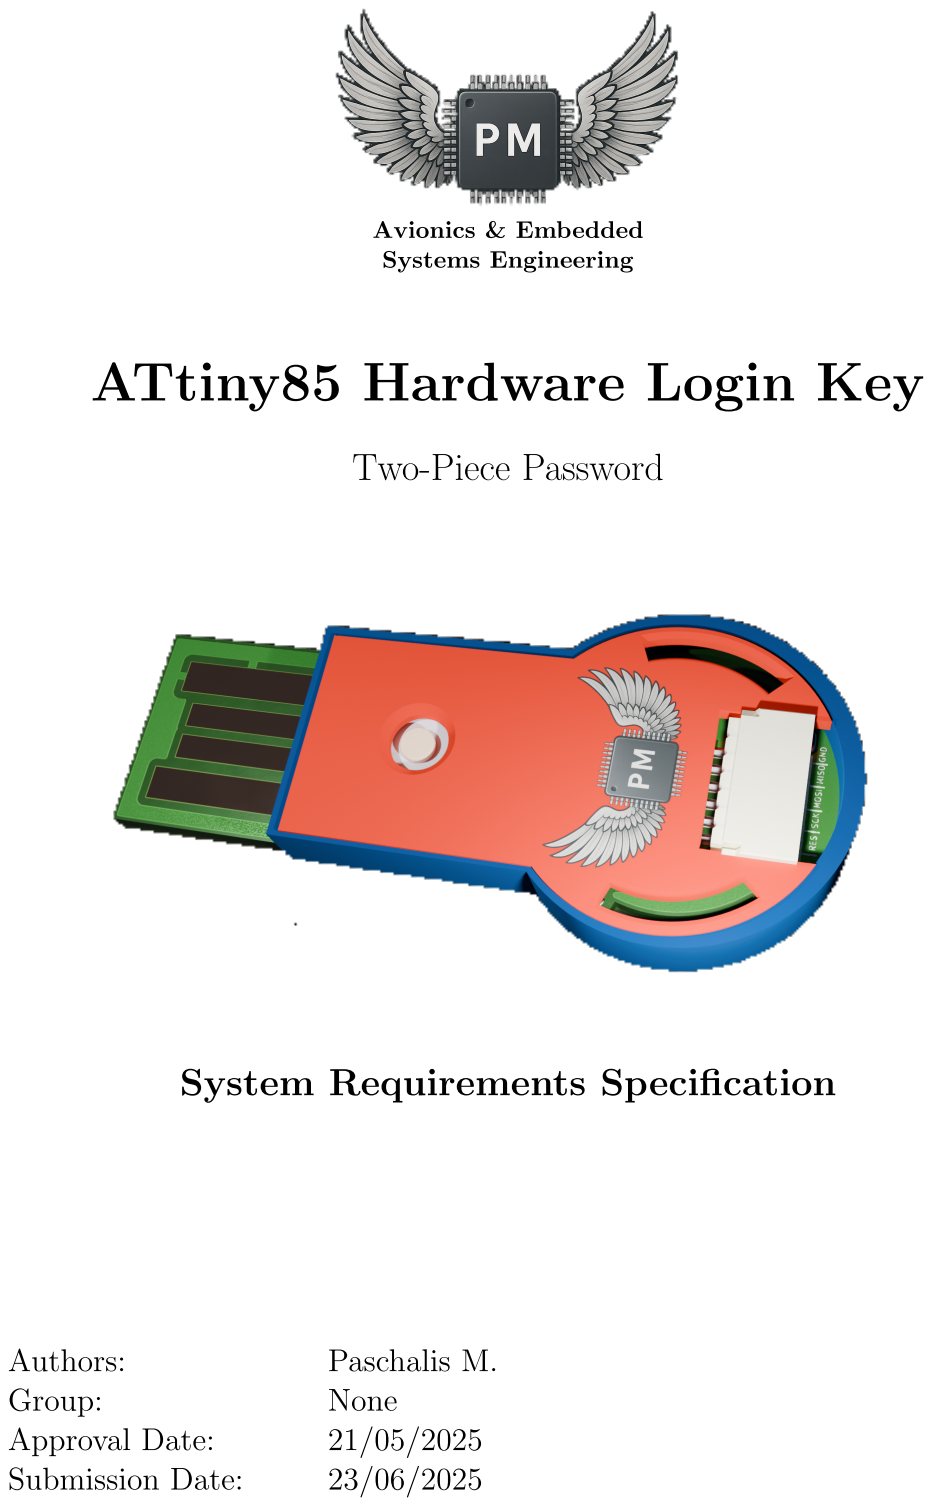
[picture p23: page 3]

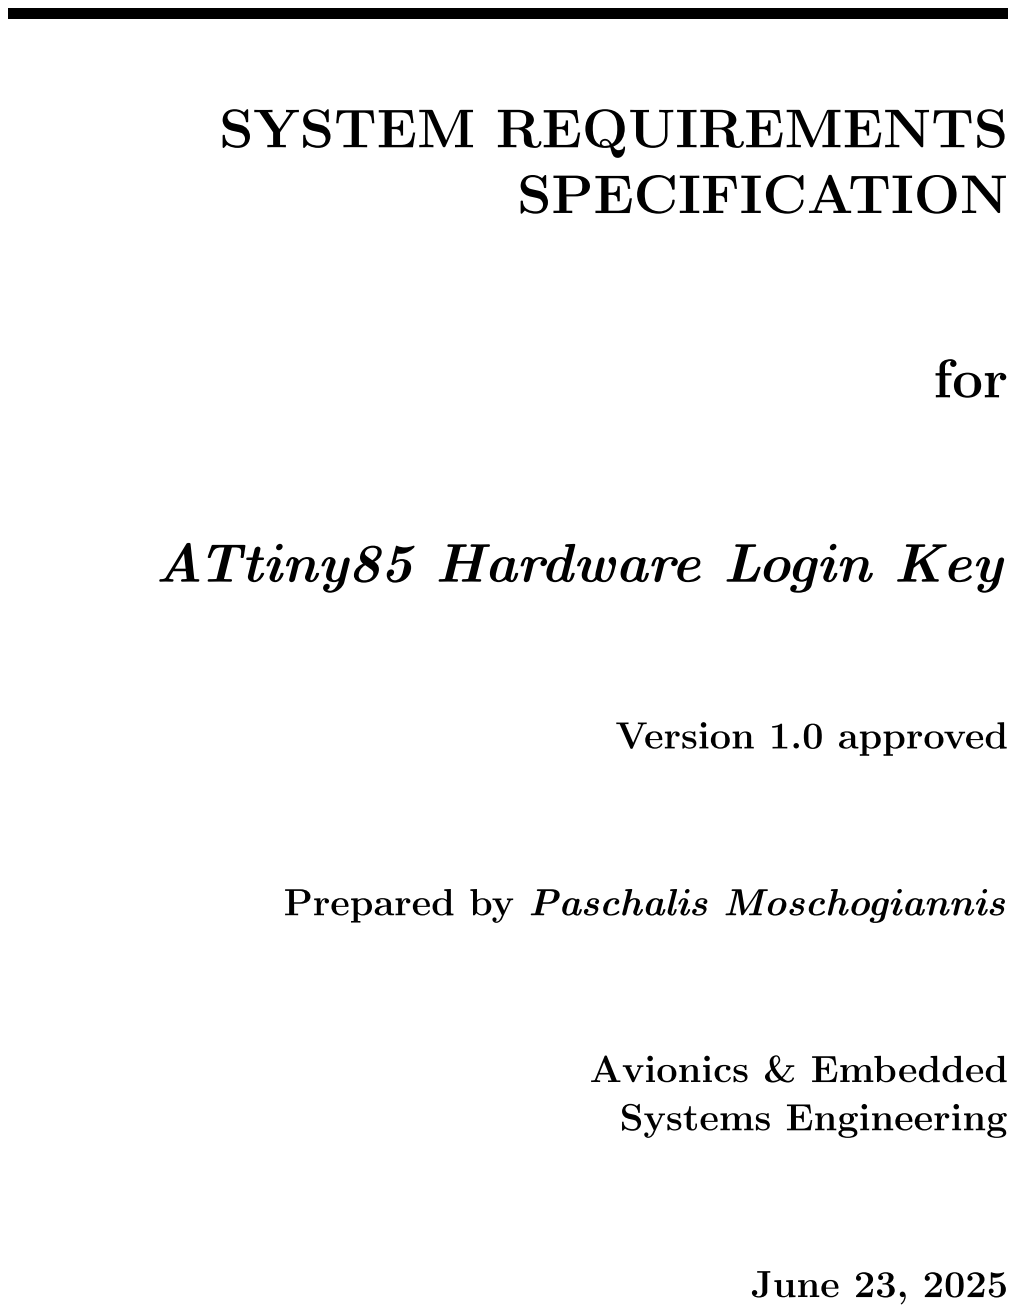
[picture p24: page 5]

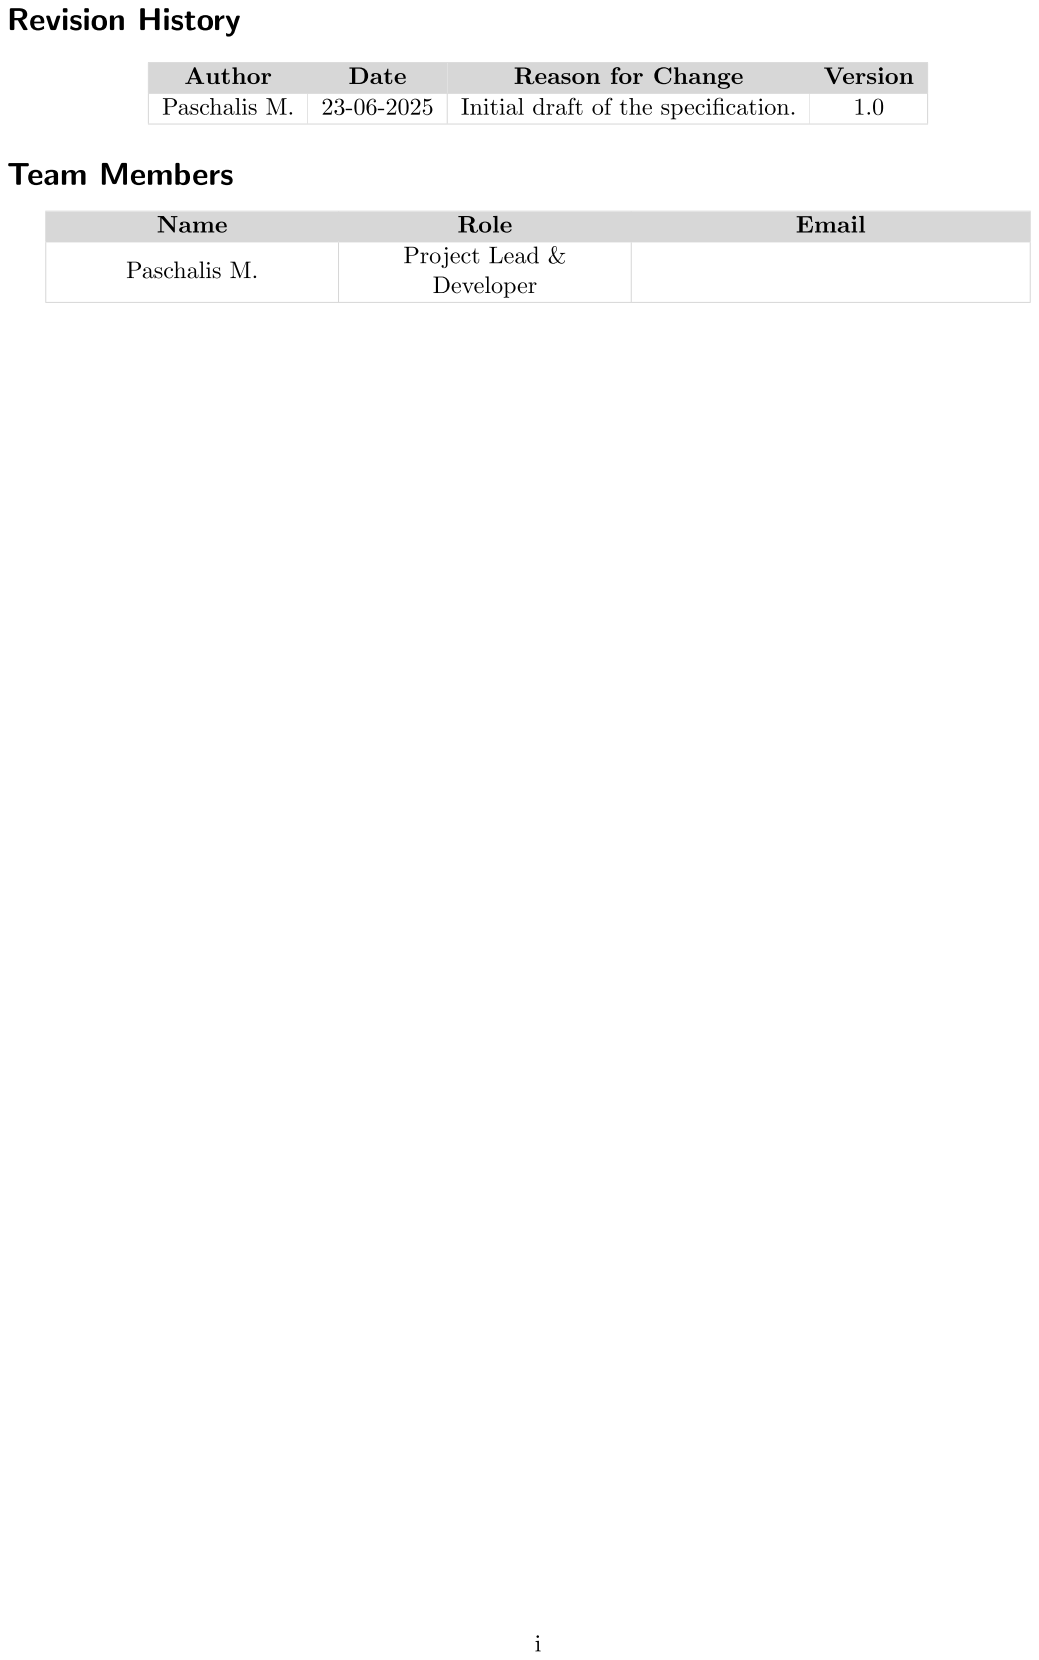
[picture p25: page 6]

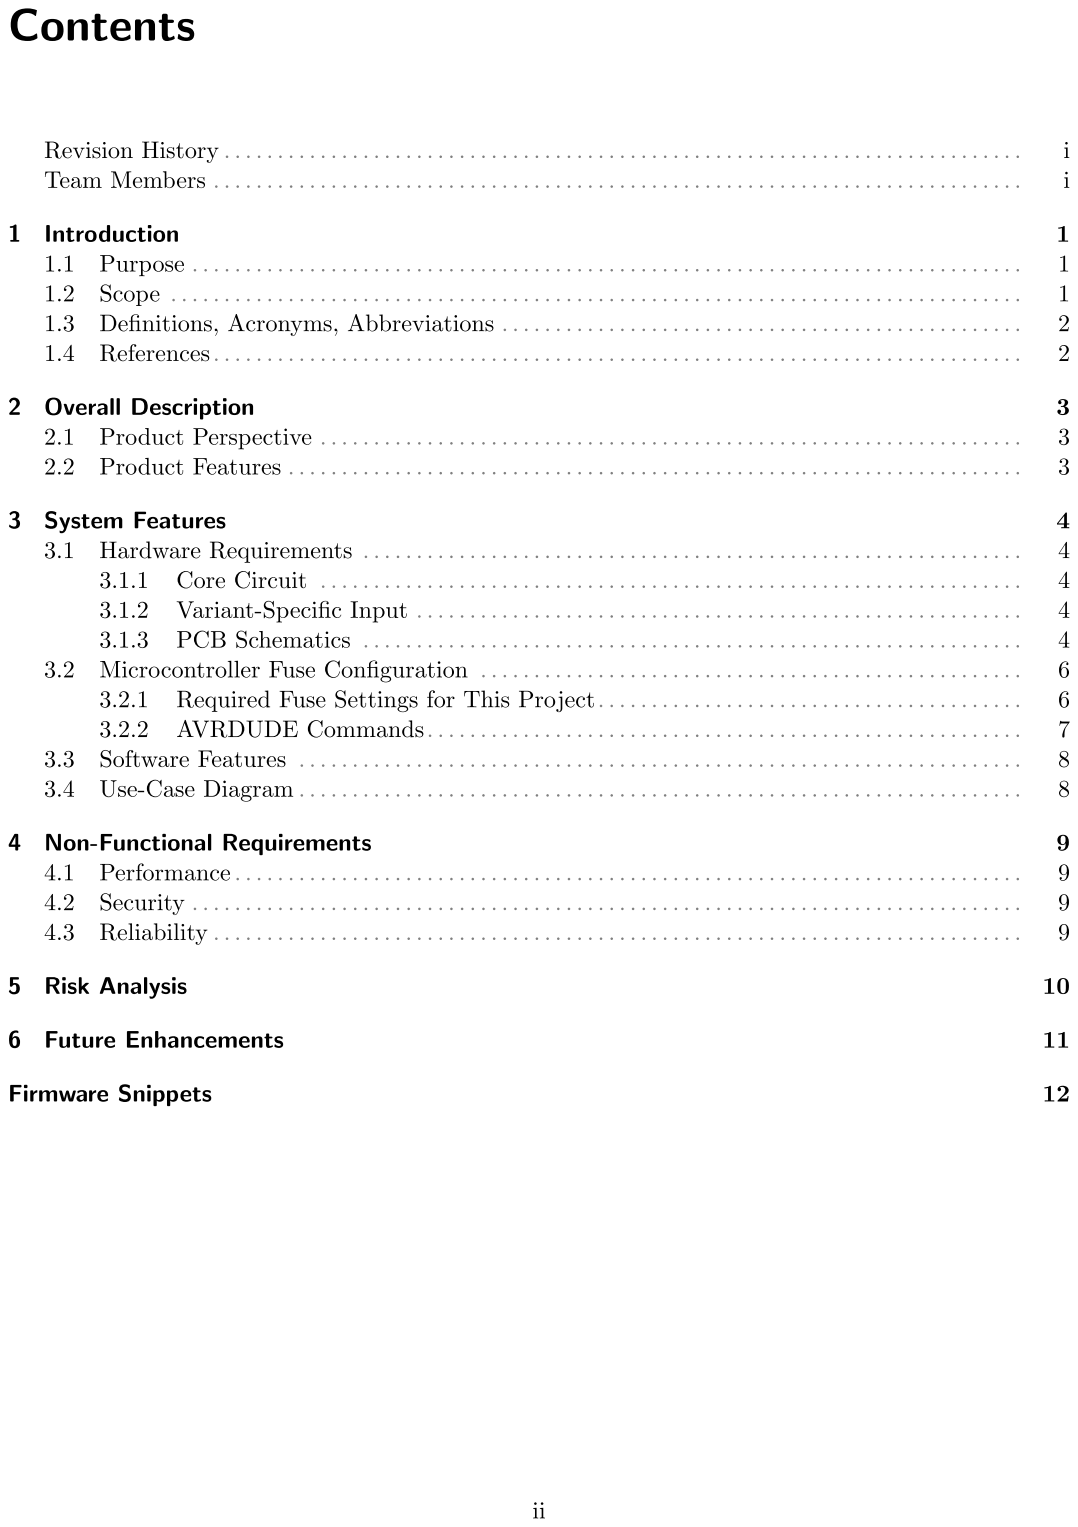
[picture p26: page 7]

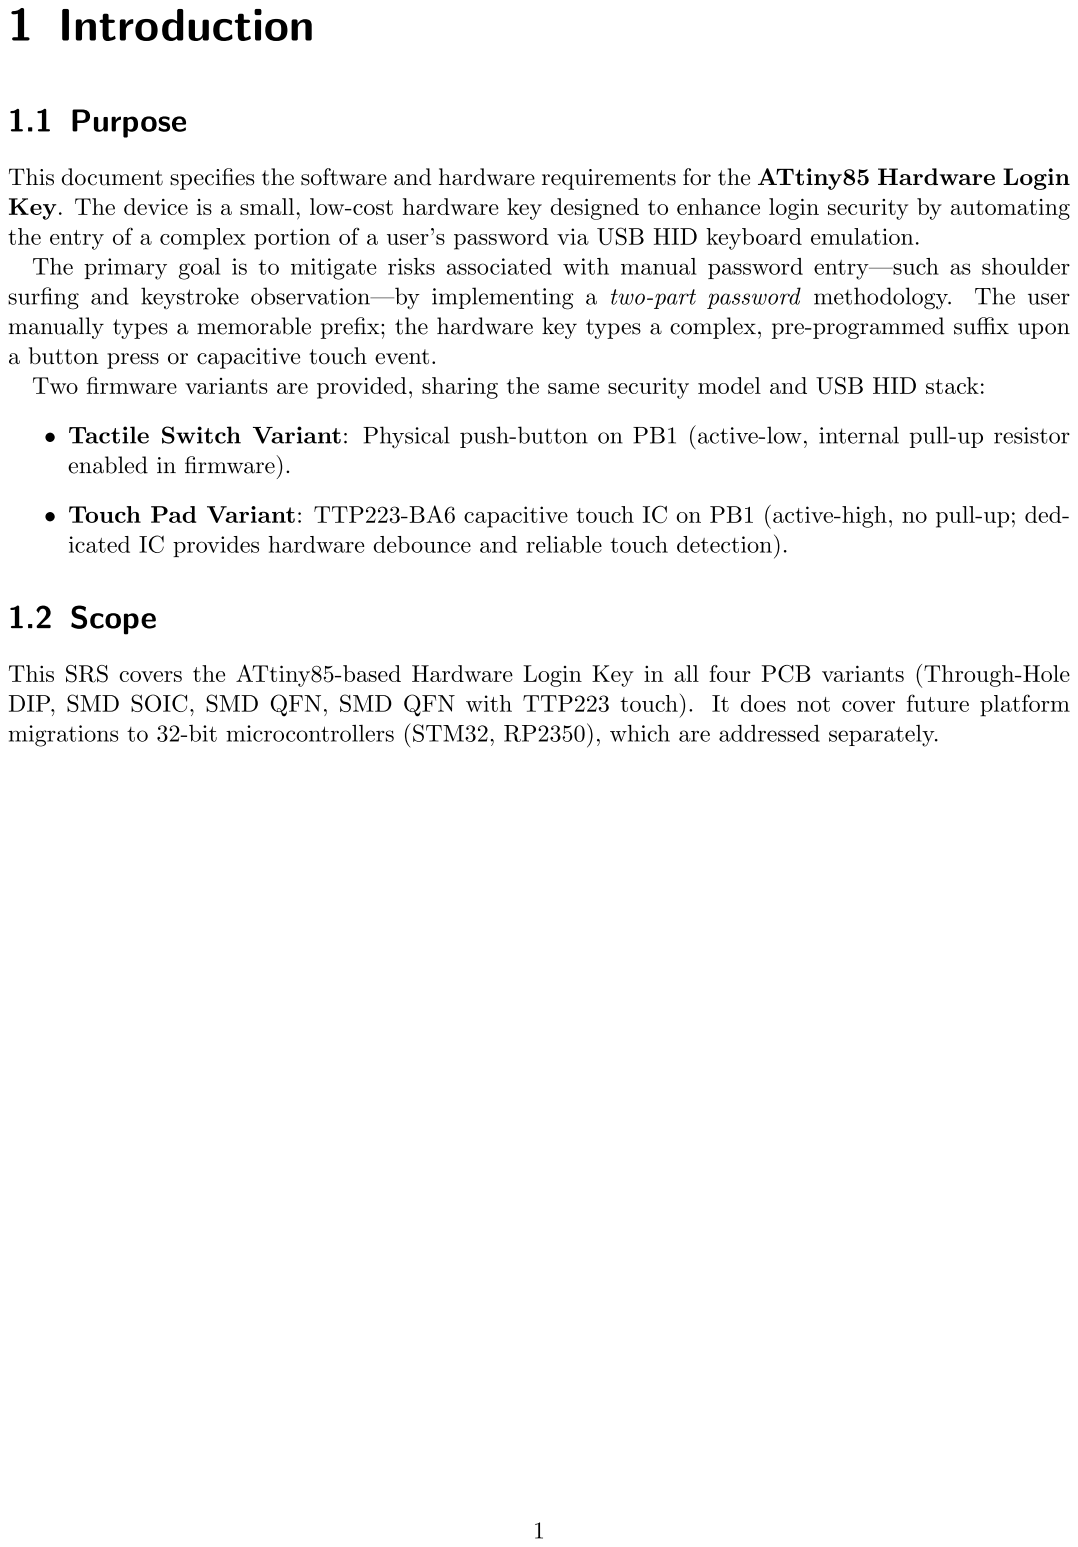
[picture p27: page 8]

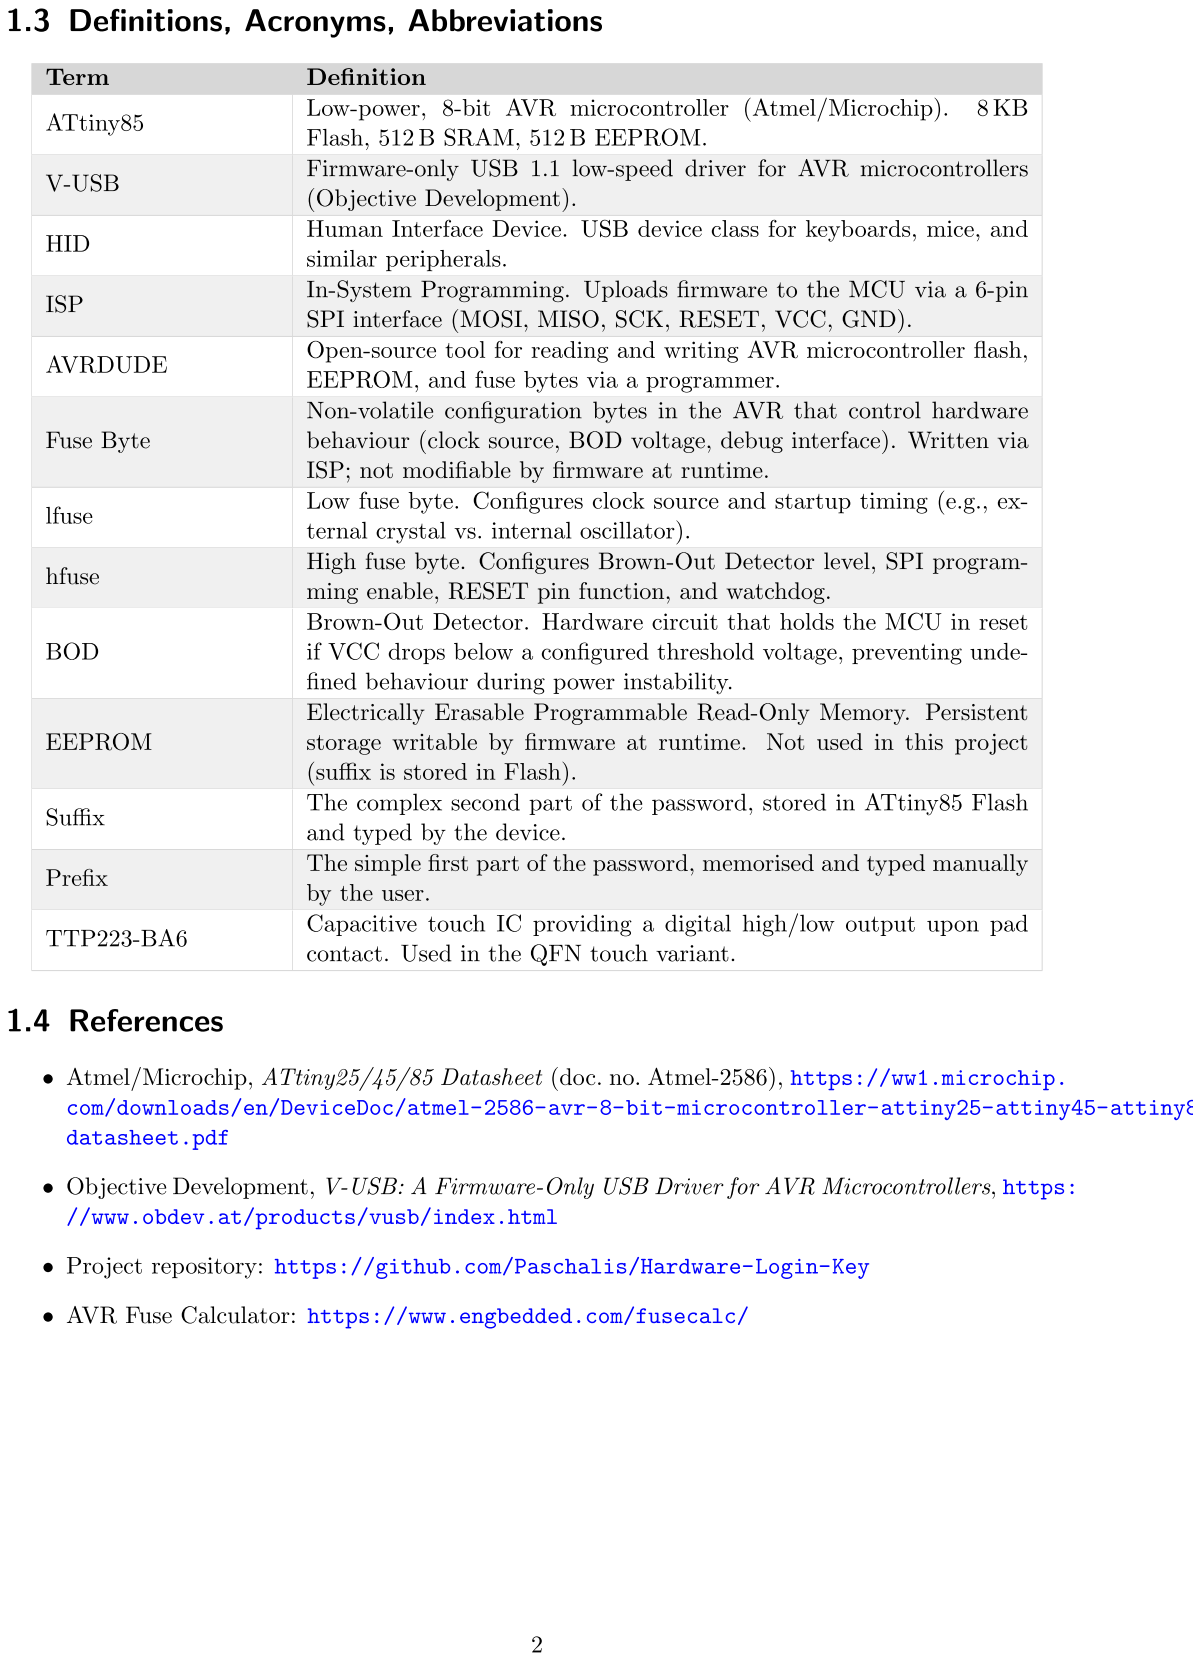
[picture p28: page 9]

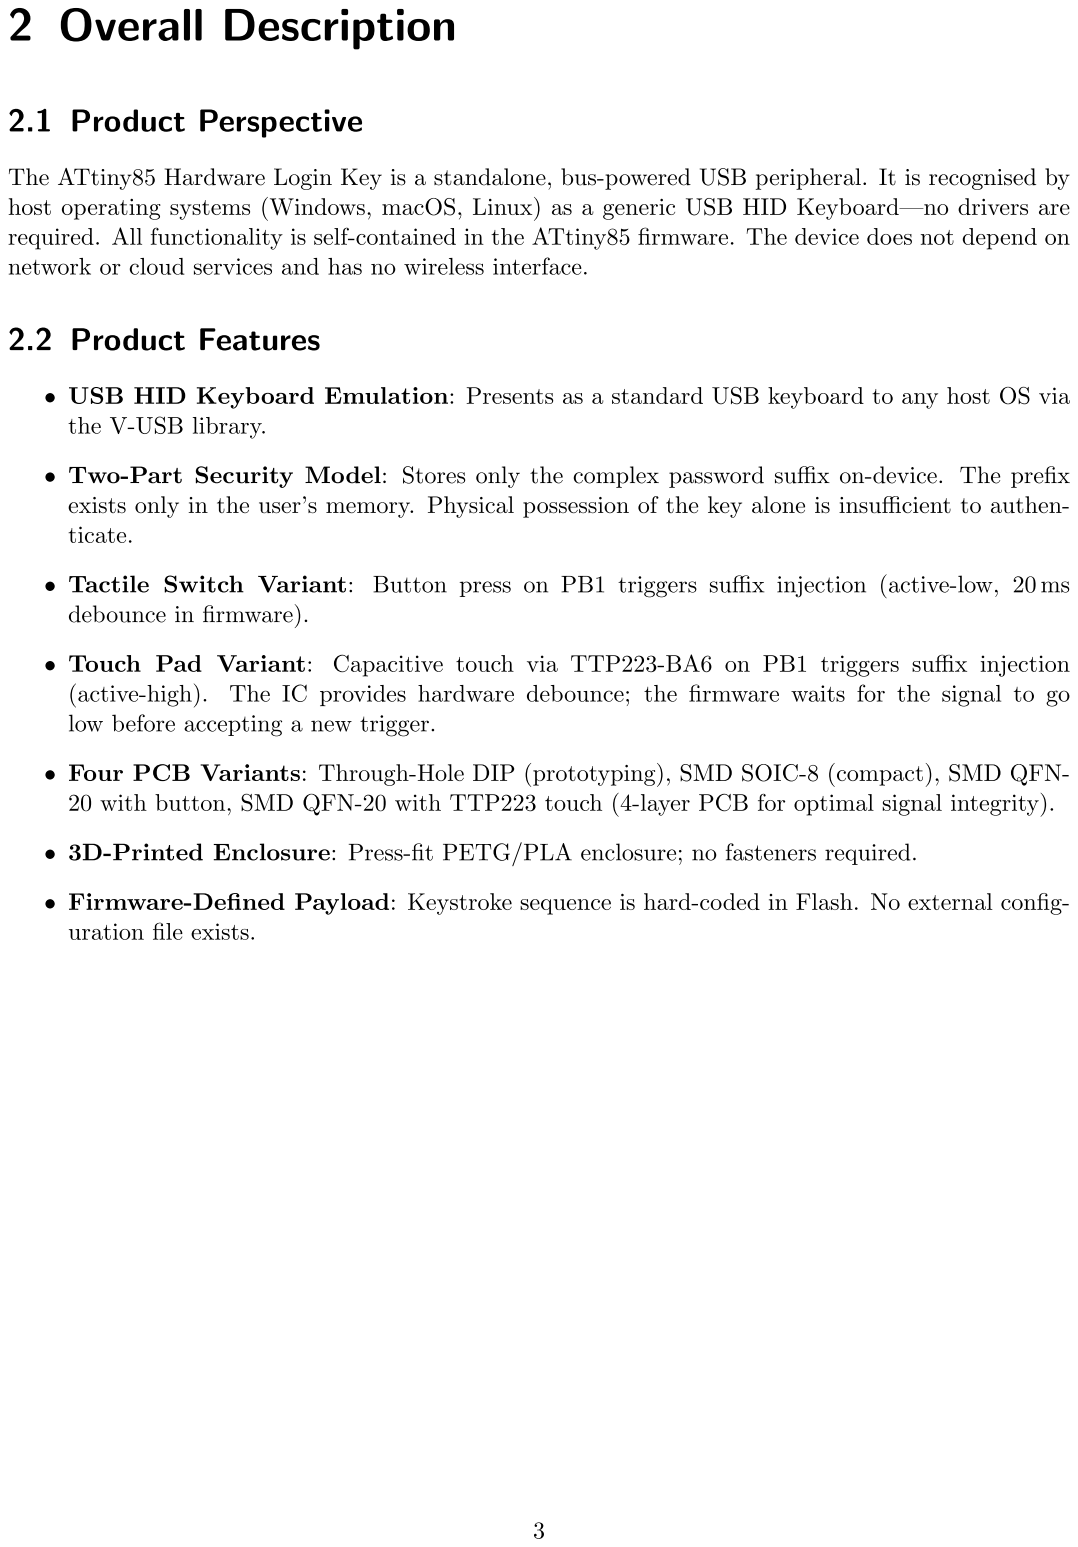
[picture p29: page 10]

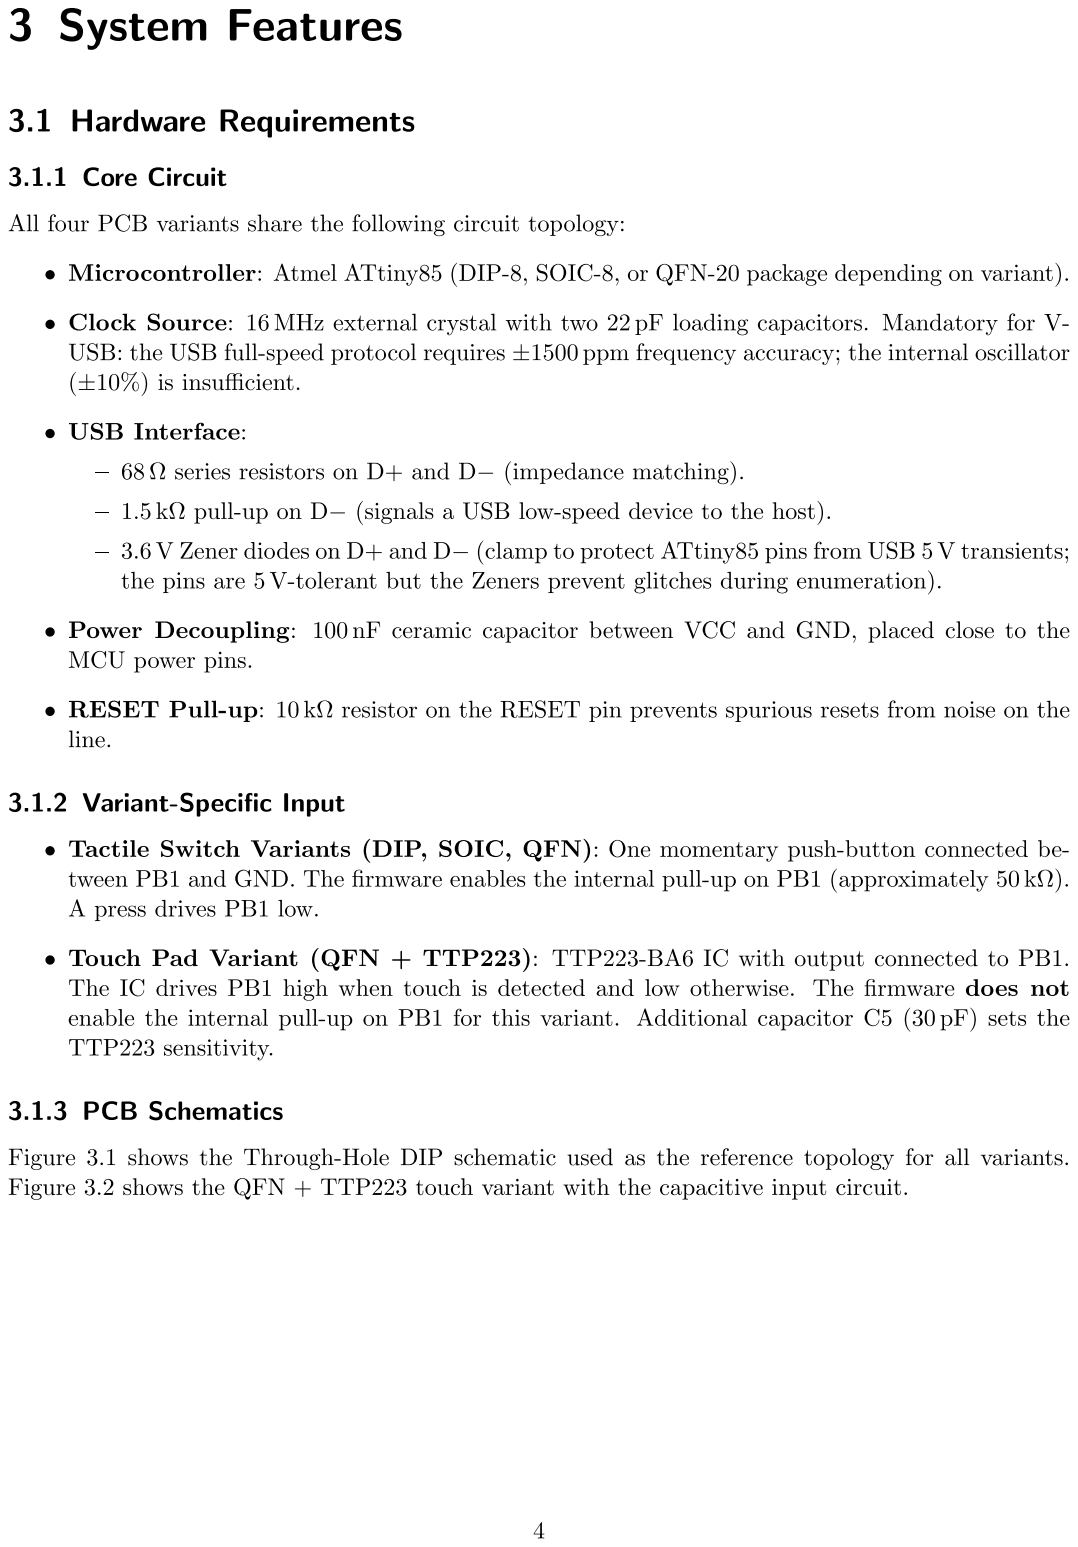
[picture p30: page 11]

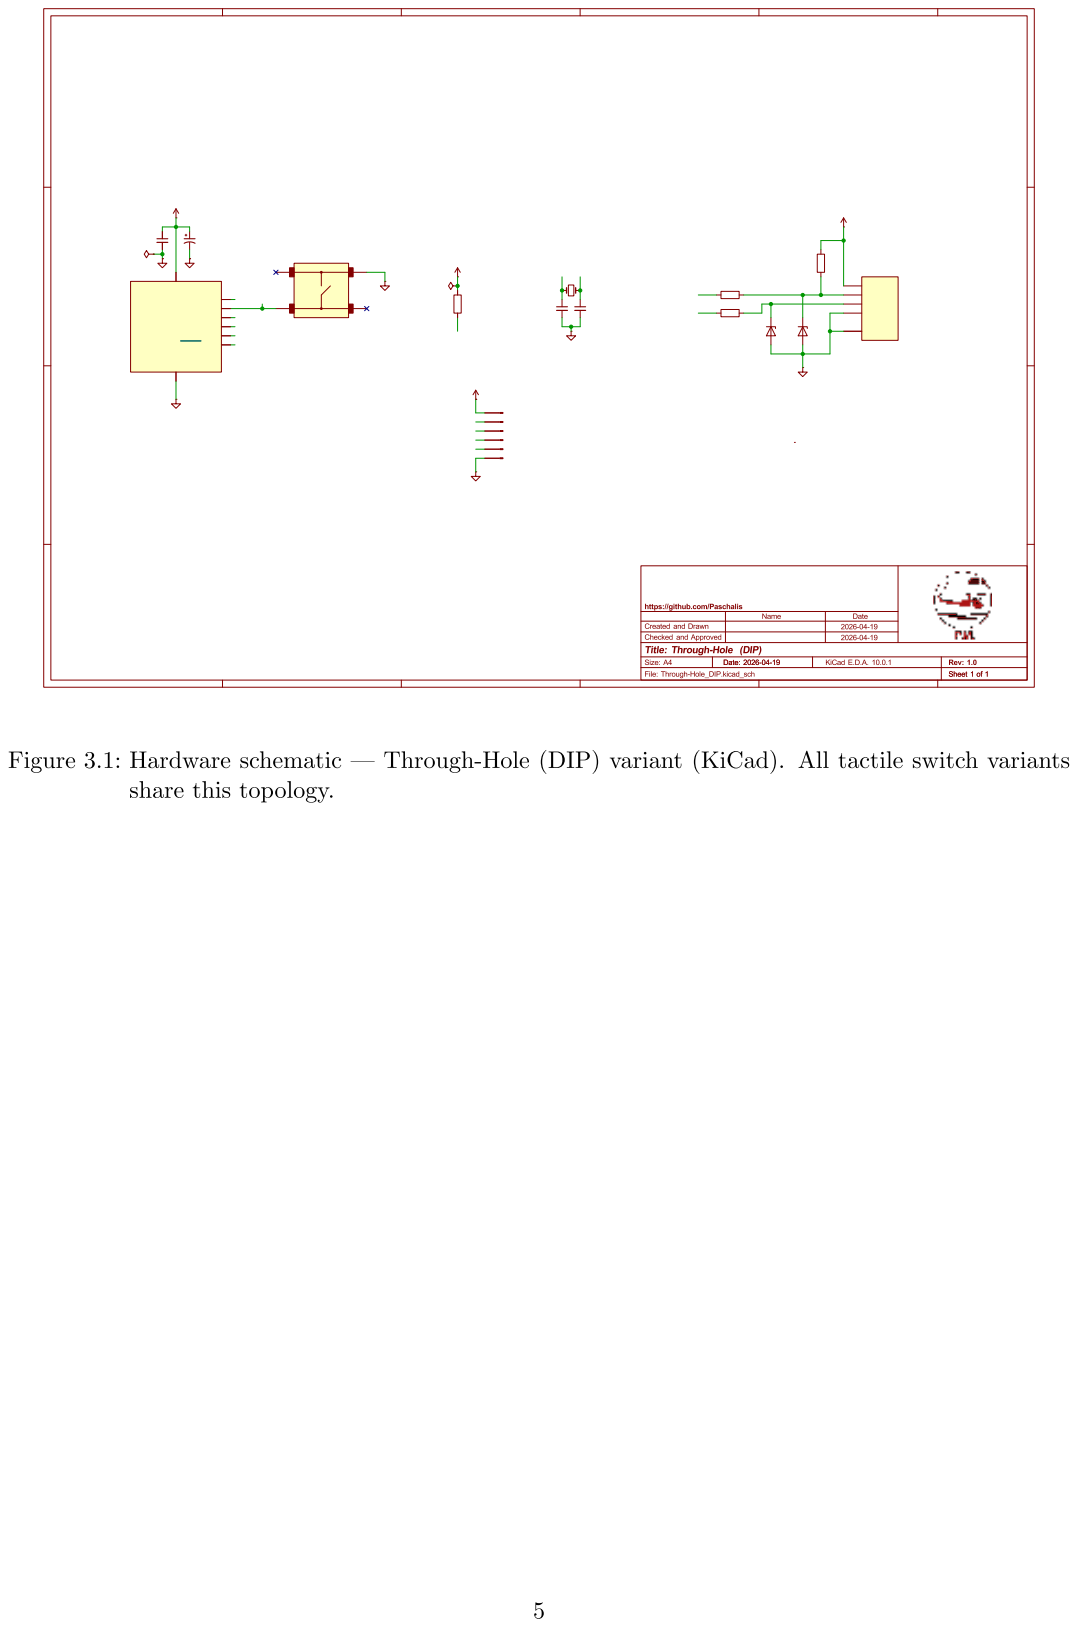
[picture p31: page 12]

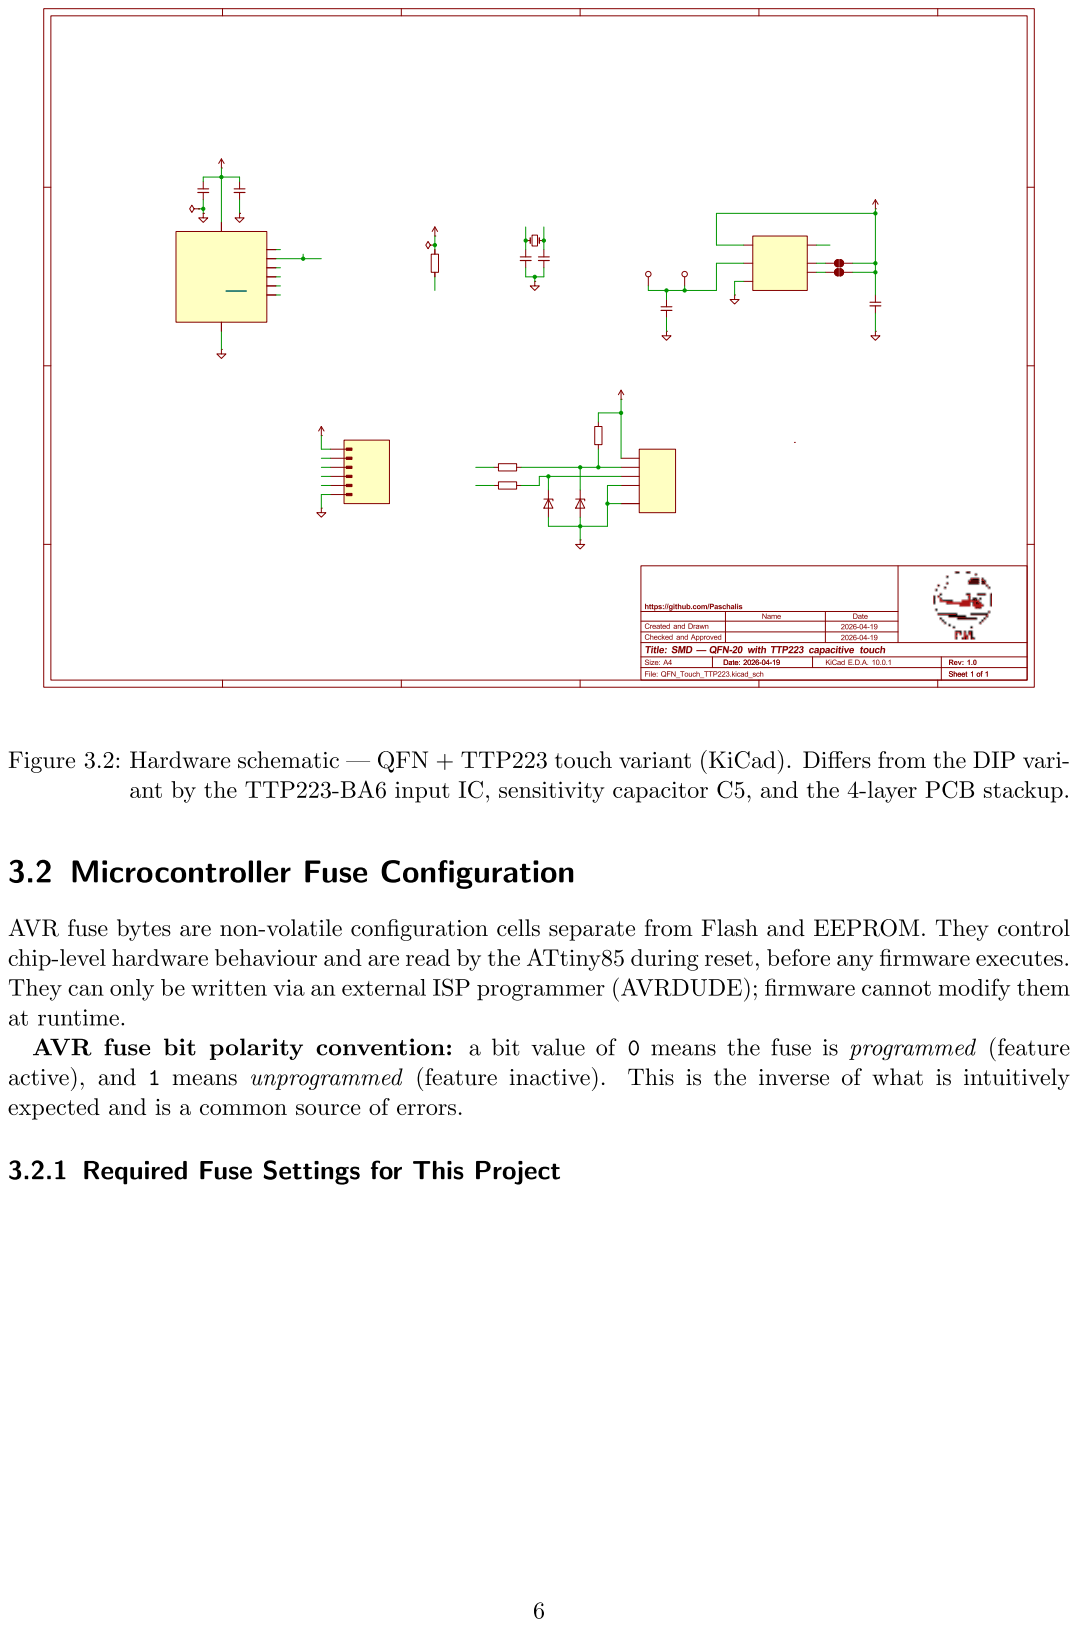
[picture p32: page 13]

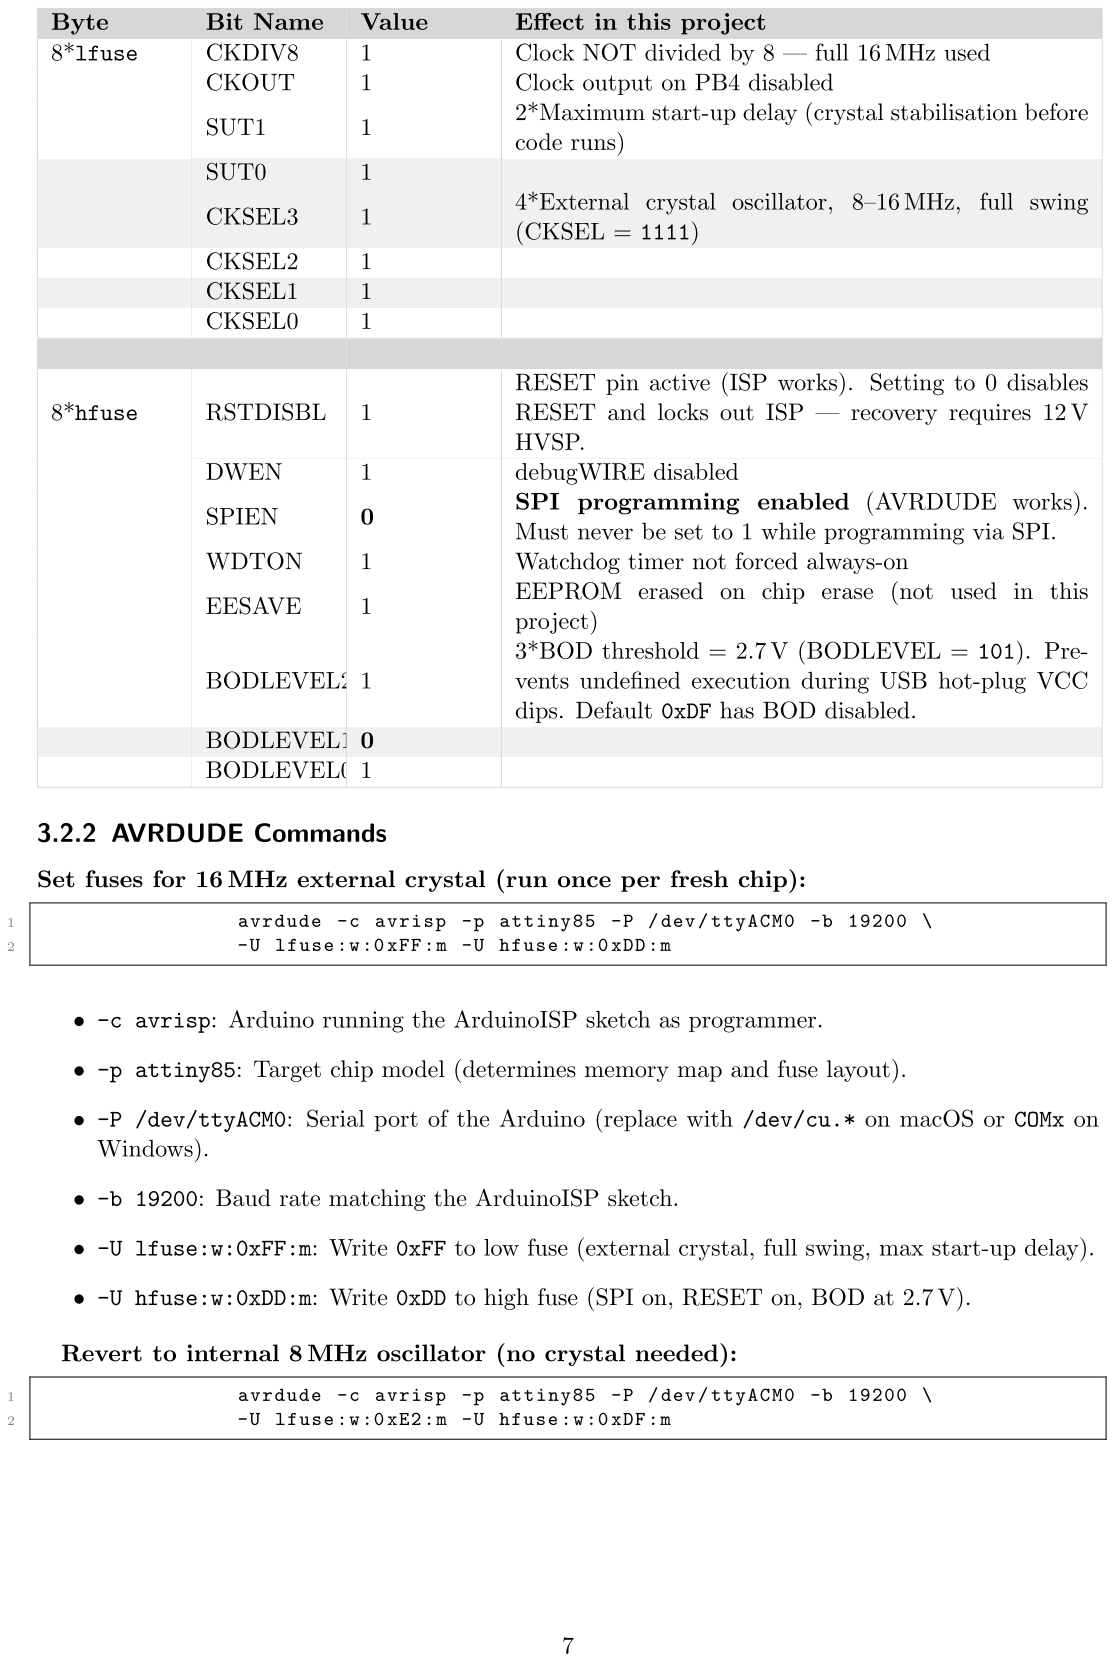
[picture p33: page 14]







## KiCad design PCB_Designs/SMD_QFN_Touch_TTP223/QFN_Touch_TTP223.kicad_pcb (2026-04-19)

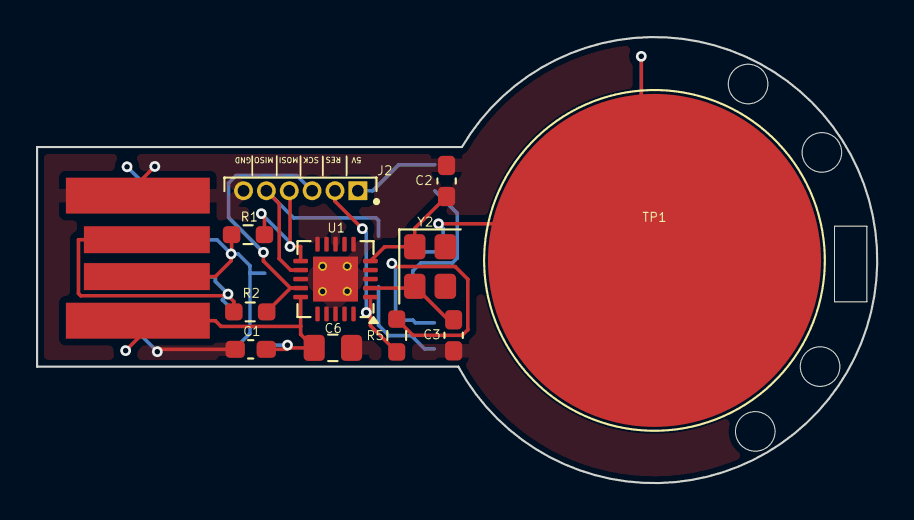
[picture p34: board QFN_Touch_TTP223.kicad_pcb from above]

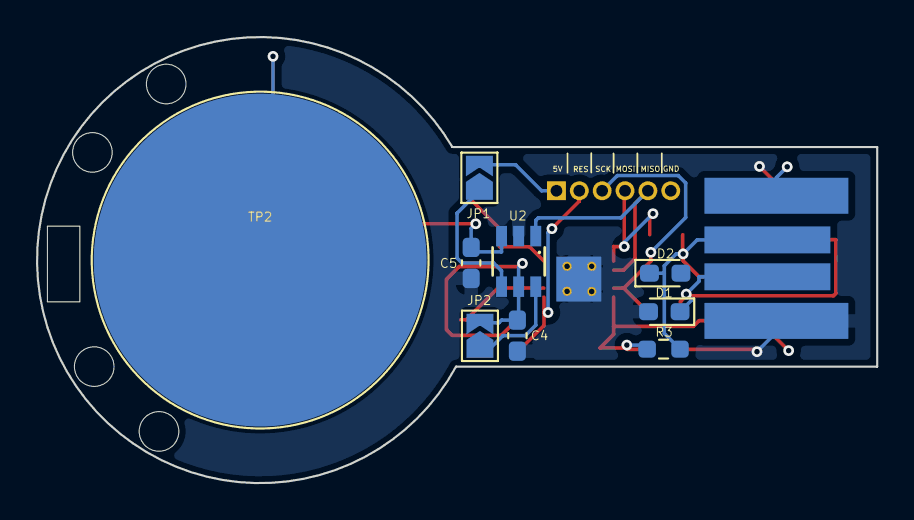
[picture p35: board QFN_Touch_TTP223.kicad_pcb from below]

Board: 4 copper layers, 46.7 x 24.8 mm, 22 parts (10 on the bottom side), 13 nets.

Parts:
C1: 100nF; C_0603_1608Metric_Pad1.08x0.95mm_HandSolder
C2, C3: 22pF; C_0603_1608Metric_Pad1.08x0.95mm_HandSolder
C4: 1uF; C_0603_1608Metric_Pad1.08x0.95mm_HandSolder
C5: 30pF; C_0603_1608Metric_Pad1.08x0.95mm_HandSolder
C6: 10μF; C_0805_2012Metric_Pad1.18x1.45mm_HandSolder
D1, D2: 3V6; D_0603_1608Metric_Pad1.05x0.95mm_HandSolder
J1, J5: USB-AM-S-X-X-TH; USB_PCB
J2: M50-3930642; HARWIN_M50-3930642
JP1, JP2: SolderJumper_2_Open; SolderJumper-2_P1.3mm_Open_TrianglePad1.0x1.5mm
R1, R2: 68R; R_0603_1608Metric_Pad0.98x0.95mm_HandSolder
R3: 1k5; R_0603_1608Metric_Pad0.98x0.95mm_HandSolder
R5: 10k; R_0603_1608Metric_Pad0.98x0.95mm_HandSolder
TP1, TP2: TestPoint; TestPoint_Pad_D3.0mm
U1: ATtiny85-20M; QFN-20-1EP_4x4mm_P0.5mm_EP2.5x2.5mm_ThermalVias
U2: TTP223-BA6; SOT23-6
Y2: 16MHz; Crystal_SMD_3225-4Pin_3.2x2.5mm

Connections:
+5V: C1.1, C4.1, C6.1, J1.01 (VCC), J2.1, J5.01 (VCC), JP1.2 (B), JP2.2 (B), R3.1, R5.1, U1.15 (VCC), U2.5 (VDD)
/Data+: J2.3, R2.2, U1.14 (PB2)
/Data-: J2.4, R1.2, U1.11 (AREF/PB0)
/MISO: J2.5, U1.12 (PB1), U2.1 (Q)
/RESET: J2.2, R5.2, U1.1 (~RESET/PB5)
/XTAL1: C3.1, U1.2 (XTAL1/PB3), Y2.2
/XTAL2: C2.1, U1.5 (XTAL2/PB4), Y2.1
GND: C1.2, C2.2, C3.2, C4.2, C5.2, C6.2, D1.2 (A), D2.2 (A), J1.04 (GND), J2.6, J5.04 (GND), U1.8 (GND), U1.21 (GND), U2.2 (VSS)
unnamed: D1.1 (K), J1.03 (D+), J5.03 (D+), R2.1
unnamed: D2.1 (K), J1.02 (D-), J5.02 (D-), R1.1, R3.2
unnamed: JP1.1 (A), U2.4 (AHLB)
unnamed: JP2.1 (A), U2.6 (TOG)
unnamed: C5.1, TP1.1, TP2.1, U2.3 (I)

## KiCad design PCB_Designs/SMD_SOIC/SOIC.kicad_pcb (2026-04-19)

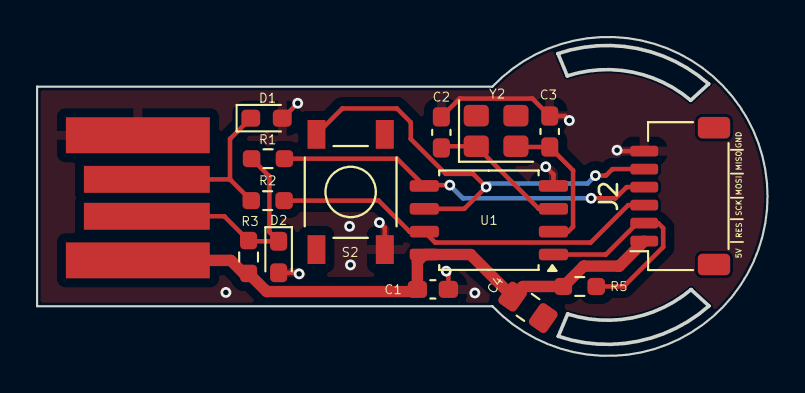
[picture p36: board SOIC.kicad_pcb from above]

Board: 2 copper layers, 40.6 x 17.7 mm, 15 parts (0 on the bottom side), 10 nets.

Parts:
C1: 100nF; C_0603_1608Metric_Pad1.08x0.95mm_HandSolder
C2, C3: 22pF; C_0603_1608Metric_Pad1.08x0.95mm_HandSolder
C4: 10μF; C_0805_2012Metric_Pad1.18x1.45mm_HandSolder
D1, D2: 3V6; D_0603_1608Metric_Pad1.05x0.95mm_HandSolder
J1: USB-AM-S-X-X-TH; USB_PCB
J2: Conn_01x06_Pin; JST_SH_SM06B-SRSS-TB_1x06-1MP_P1.00mm_Horizontal
R1, R2: 68R; R_0603_1608Metric_Pad0.98x0.95mm_HandSolder
R3: 1k5; R_0603_1608Metric_Pad0.98x0.95mm_HandSolder
R5: 10k; R_0603_1608Metric_Pad0.98x0.95mm_HandSolder
S2: PTS525SM15SMTR2LFS; SW_PTS525SM15SMTR2LFS
U1: ATtiny85-20P; SOIC-8_5.3x5.3mm_P1.27mm
Y2: 16MHz; Crystal_SMD_3225-4Pin_3.2x2.5mm

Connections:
+5V: C1.1, C4.1, J1.01 (VCC), J2.1, R3.1, R5.1, U1.8 (VCC)
/Data+: J2.3, R2.2, U1.7 (PB2)
/Data-: J2.4, R1.2, U1.5 (AREF/PB0)
/MISO: J2.5, S2.2, U1.6 (PB1)
/RESET: J2.2, R5.2, U1.1 (~RESET/PB5)
/XTAL1: C3.1, U1.2 (XTAL1/PB3), Y2.2
/XTAL2: C2.1, U1.3 (XTAL2/PB4), Y2.1
GND: C1.2, C2.2, C3.2, C4.2, D1.2 (A), D2.2 (A), J1.04 (GND), J2.6, S2.3, U1.4 (GND)
unnamed: D1.1 (K), J1.03 (D+), R2.1
unnamed: D2.1 (K), J1.02 (D-), R1.1, R3.2

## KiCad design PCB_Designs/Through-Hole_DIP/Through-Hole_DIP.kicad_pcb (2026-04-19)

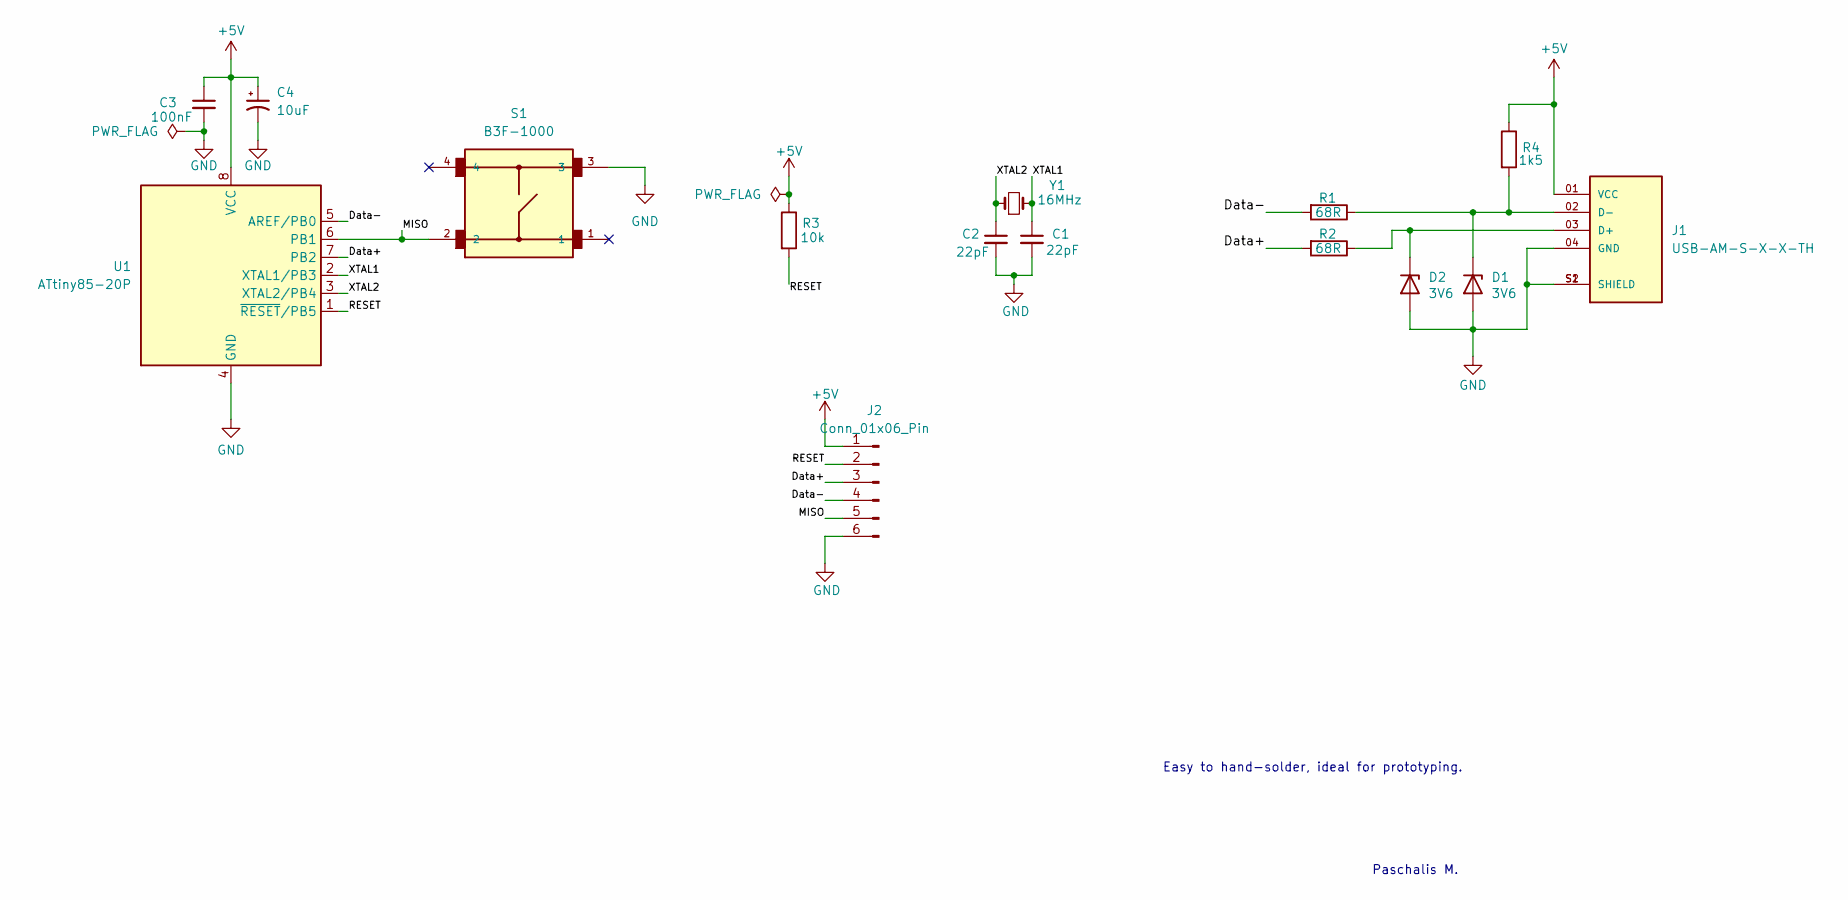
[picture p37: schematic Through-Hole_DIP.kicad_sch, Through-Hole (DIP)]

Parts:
C1, C2: 22pF; C_Disc_D5.0mm_W2.5mm_P5.00mm
C3: 100nF; C_Disc_D5.0mm_W2.5mm_P5.00mm
C4: 10uF; CP_Radial_D4.0mm_P2.00mm
D1, D2: 3V6; D_DO-15_P10.16mm_Horizontal
J1: USB-AM-S-X-X-TH; SAMTEC_USB-AM-S-X-X-TH; PARTREV U
J2: Conn_01x06_Pin; Molex_PicoBlade_53047-0610_1x06_P1.25mm_Vertical
R1, R2: 68R; R_Axial_DIN0204_L3.6mm_D1.6mm_P5.08mm_Horizontal
R3: 10k; R_Axial_DIN0204_L3.6mm_D1.6mm_P5.08mm_Horizontal
R4: 1k5; R_Axial_DIN0204_L3.6mm_D1.6mm_P5.08mm_Horizontal
S1: B3F-1000; SW_B3F-1000
U1: ATtiny85-20P; DIP-8_W7.62mm
Y1: 16MHz; Crystal_HC49-4H_Vertical

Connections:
+5V: C3.1, C4.1, J1.01 (VCC), J2.1, R3.1, R4.1, U1.8 (VCC)
/Data+: J2.3, R2.2, U1.7 (PB2)
/Data-: J2.4, R1.2, U1.5 (AREF/PB0)
/MISO: J2.5, S1.2, U1.6 (PB1)
/RESET: J2.2, R3.2, U1.1 (~RESET/PB5)
/XTAL1: C1.1, U1.2 (XTAL1/PB3), Y1.2
/XTAL2: C2.1, U1.3 (XTAL2/PB4), Y1.1
GND: C1.2, C2.2, C3.2, C4.2, D1.2 (A), D2.2 (A), J1.04 (GND), J1.S1 (SHIELD), J1.S2 (SHIELD), J2.6, S1.3, U1.4 (GND)
unnamed: D1.1 (K), J1.02 (D-), R1.1, R4.2
unnamed: D2.1 (K), J1.03 (D+), R2.1

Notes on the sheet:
Paschalis M.
Easy to hand-solder, ideal for prototyping.

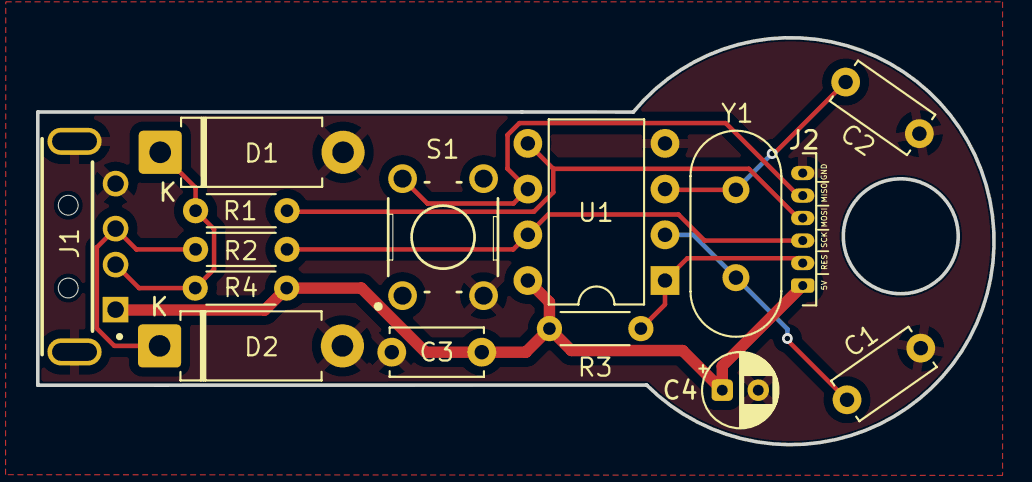
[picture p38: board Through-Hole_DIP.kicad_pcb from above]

Board: 2 copper layers, 53.1 x 22.6 mm, 15 parts (0 on the bottom side), 10 nets.

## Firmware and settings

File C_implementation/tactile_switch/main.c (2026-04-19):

#include <avr/io.h>
#include <avr/wdt.h>
#include <avr/interrupt.h>
#include <util/delay.h>
#include "usbdrv/usbdrv.h"

// --- Pin Definitions ---
#define BUTTON_PIN  PB1 // Button is on PB1

// --- HID Keyboard Report Descriptor ---
PROGMEM const char usbHidReportDescriptor[63] = {
    0x05, 0x01, 0x09, 0x06, 0xa1, 0x01, 0x75, 0x01, 0x95, 0x08, 0x05, 0x07, 0x19, 0xe0, 0x29, 0xe7,
    0x15, 0x00, 0x25, 0x01, 0x81, 0x02, 0x95, 0x01, 0x75, 0x08, 0x81, 0x03, 0x95, 0x05, 0x75, 0x01,
    0x05, 0x08, 0x19, 0x01, 0x29, 0x05, 0x91, 0x02, 0x95, 0x01, 0x75, 0x03, 0x91, 0x03, 0x95, 0x06,
    0x75, 0x08, 0x15, 0x00, 0x25, 0x65, 0x05, 0x07, 0x19, 0x00, 0x29, 0x65, 0x81, 0x00, 0xc0
};

// This is the COMPLEX SUFFIX of your password.
static const char password_suffix[] = "!#2025_complex";

// Function to send a keystroke
void send_key(uchar key_code, uchar modifier) {
    static uchar reportBuffer[8] = {0};
    reportBuffer[0] = modifier;
    reportBuffer[2] = key_code;

    while (!usbInterruptIsReady()) {
        usbPoll();
        _delay_ms(5);
    }
    usbSetInterrupt(reportBuffer, sizeof(reportBuffer));

    reportBuffer[0] = 0;
    reportBuffer[2] = 0;
    while (!usbInterruptIsReady()) {
        usbPoll();
        _delay_ms(5);
    }
    usbSetInterrupt(reportBuffer, sizeof(reportBuffer));
}

// Function to type out the password string
void type_password() {
    for (int i = 0; i < sizeof(password_suffix) - 1; i++) {
        char c = password_suffix[i];
        uchar key_code = 0;
        uchar modifier = 0;

        if (c >= 'a' && c <= 'z') { key_code = c - 'a' + 4; }
        else if (c >= 'A' && c <= 'Z') { key_code = c - 'A' + 4; modifier = 0x02; }
        else if (c >= '1' && c <= '9') { key_code = c - '1' + 30; }
        else if (c == '0') { key_code = 39; }
        else if (c == '!') { key_code = 30; modifier = 0x02; }
        else if (c == '#') { key_code = 32; modifier = 0x02; }
        else if (c == '_') { key_code = 45; modifier = 0x02; }
        else if (c == '-') { key_code = 45; }

        if (key_code != 0) {
            send_key(key_code, modifier);
            _delay_ms(50);
        }
    }
    send_key(40, 0); // Press Enter
}

int main(void) {
    // --- Setup ---
    wdt_disable();

    // Setup Button Pin
    DDRB &= ~(1 << BUTTON_PIN); // Set BUTTON_PIN (PB1) as input
    PORTB |= (1 << BUTTON_PIN); // Enable internal pull-up for BUTTON_PIN

    // Initialize V-USB
    usbInit();
    usbDeviceDisconnect();
    for (int i = 0; i < 250; i++) { _delay_ms(1); }
    usbDeviceConnect();

    sei(); // Enable global interrupts

    // --- Main Loop ---
    while (1) {
        usbPoll();
        if (!(PINB & (1 << BUTTON_PIN))) { // Check if button is pressed
            _delay_ms(20); // Debounce
            if (!(PINB & (1 << BUTTON_PIN))) {
                type_password();
                // Wait for button to be released
                while (!(PINB & (1 << BUTTON_PIN))) {
                    usbPoll();
                }
            }
        }
    }
    return 0;
}

// --- V-USB Required Callback Functions ---

// This function is called by V-USB for every incoming control message.
// We are only a keyboard, so we don't need to handle any custom requests.
// We just return 0 to indicate that we haven't handled the request.
USB_PUBLIC uchar usbFunctionSetup(uchar data[8]) {
    usbRequest_t    *rq = (void *)data;

    // The host requests the HID report descriptor.
    if((rq->bmRequestType & USBRQ_TYPE_MASK) == USBRQ_TYPE_STANDARD){
        if(rq->bRequest == USBRQ_GET_DESCRIPTOR){
            if(rq->wValue.bytes[1] == USBDESCR_HID_REPORT){
                usbMsgPtr = (void *)usbHidReportDescriptor;
                return sizeof(usbHidReportDescriptor);
            }
        }
    }
    // All other requests are not handled.
    return 0;
}

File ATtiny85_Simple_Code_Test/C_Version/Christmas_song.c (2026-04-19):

#include <avr/io.h>
#include "notes.h"

// --- Microcontroller Clock Speed ---
#ifndef F_CPU
#define F_CPU 8000000UL // 8MHz clock speed for ATtiny85
#endif

// --- Pin Definition ---
#define SPEAKER_PIN PB1 // Using PB1 (physical pin 6 on ATtiny85)

// --- Note and Melody Structure ---
typedef struct {
    uint16_t frequency;
    uint16_t duration;
} Note;

// --- Tempo and Note Durations (in milliseconds) ---
#define TEMPO 140
#define WHOLE_NOTE     (uint16_t)((60000.0 / TEMPO) * 4)
#define HALF_NOTE      (uint16_t)((60000.0 / TEMPO) * 2)
#define QUARTER_NOTE   (uint16_t)(60000.0 / TEMPO)
#define EIGHTH_NOTE    (uint16_t)((60000.0 / TEMPO) / 2)
#define SIXTEENTH_NOTE (uint16_t)((60000.0 / TEMPO) / 4)

// --- Song 1: "Jingle Bells" ---
Note jingle_bells_melody[] = {
    // Verse
    {NOTE_E5, QUARTER_NOTE}, {NOTE_E5, QUARTER_NOTE}, {NOTE_E5, HALF_NOTE},
    {NOTE_E5, QUARTER_NOTE}, {NOTE_E5, QUARTER_NOTE}, {NOTE_E5, HALF_NOTE},
    {NOTE_E5, QUARTER_NOTE}, {NOTE_G5, QUARTER_NOTE}, {NOTE_C5, QUARTER_NOTE + EIGHTH_NOTE}, {NOTE_D5, EIGHTH_NOTE}, {NOTE_E5, HALF_NOTE},
    {NOTE_F5, QUARTER_NOTE}, {NOTE_F5, QUARTER_NOTE}, {NOTE_F5, QUARTER_NOTE + EIGHTH_NOTE}, {NOTE_F5, EIGHTH_NOTE},
    {NOTE_F5, QUARTER_NOTE}, {NOTE_E5, QUARTER_NOTE}, {NOTE_E5, EIGHTH_NOTE}, {NOTE_E5, EIGHTH_NOTE},
    {NOTE_E5, QUARTER_NOTE}, {NOTE_D5, QUARTER_NOTE}, {NOTE_D5, QUARTER_NOTE}, {NOTE_E5, QUARTER_NOTE},
    {NOTE_D5, HALF_NOTE}, {NOTE_G5, HALF_NOTE}, {NOTE_REST, QUARTER_NOTE},
    // Chorus
    {NOTE_E5, QUARTER_NOTE}, {NOTE_E5, QUARTER_NOTE}, {NOTE_E5, HALF_NOTE},
    {NOTE_E5, QUARTER_NOTE}, {NOTE_E5, QUARTER_NOTE}, {NOTE_E5, HALF_NOTE},
    {NOTE_E5, QUARTER_NOTE}, {NOTE_G5, QUARTER_NOTE}, {NOTE_C5, QUARTER_NOTE + EIGHTH_NOTE}, {NOTE_D5, EIGHTH_NOTE}, {NOTE_E5, HALF_NOTE},
    {NOTE_F5, QUARTER_NOTE}, {NOTE_F5, QUARTER_NOTE}, {NOTE_F5, QUARTER_NOTE + EIGHTH_NOTE}, {NOTE_F5, EIGHTH_NOTE},
    {NOTE_F5, QUARTER_NOTE}, {NOTE_E5, QUARTER_NOTE}, {NOTE_E5, QUARTER_NOTE},
    {NOTE_G5, QUARTER_NOTE}, {NOTE_G5, QUARTER_NOTE}, {NOTE_F5, QUARTER_NOTE}, {NOTE_D5, QUARTER_NOTE}, {NOTE_C5, HALF_NOTE}, {NOTE_REST, QUARTER_NOTE}
};
int jingle_bells_length = sizeof(jingle_bells_melody) / sizeof(Note);

// --- Song 2: "We Wish You a Merry Christmas" ---
Note we_wish_you_melody[] = {
    {NOTE_G4, QUARTER_NOTE}, {NOTE_C5, QUARTER_NOTE}, {NOTE_C5, EIGHTH_NOTE}, {NOTE_D5, EIGHTH_NOTE}, {NOTE_C5, QUARTER_NOTE}, {NOTE_B4, QUARTER_NOTE}, {NOTE_A4, HALF_NOTE},
    {NOTE_A4, QUARTER_NOTE}, {NOTE_D5, QUARTER_NOTE}, {NOTE_D5, EIGHTH_NOTE}, {NOTE_E5, EIGHTH_NOTE}, {NOTE_D5, QUARTER_NOTE}, {NOTE_C5, QUARTER_NOTE}, {NOTE_B4, HALF_NOTE},
    {NOTE_B4, QUARTER_NOTE}, {NOTE_E5, QUARTER_NOTE}, {NOTE_E5, EIGHTH_NOTE}, {NOTE_F5, EIGHTH_NOTE}, {NOTE_E5, QUARTER_NOTE}, {NOTE_D5, QUARTER_NOTE}, {NOTE_C5, HALF_NOTE},
    {NOTE_G4, QUARTER_NOTE}, {NOTE_G4, QUARTER_NOTE}, {NOTE_A4, QUARTER_NOTE}, {NOTE_D5, HALF_NOTE}, {NOTE_B4, QUARTER_NOTE}, {NOTE_C5, HALF_NOTE}, {NOTE_REST, HALF_NOTE}
};
int we_wish_you_length = sizeof(we_wish_you_melody) / sizeof(Note);

// --- NEW: Song 3: "Deck the Halls" ---
Note deck_the_halls_melody[] = {
    {NOTE_G5, QUARTER_NOTE}, {NOTE_F5, EIGHTH_NOTE}, {NOTE_E5, QUARTER_NOTE}, {NOTE_D5, EIGHTH_NOTE}, {NOTE_C5, QUARTER_NOTE}, {NOTE_D5, QUARTER_NOTE}, {NOTE_E5, QUARTER_NOTE}, {NOTE_C5, QUARTER_NOTE},
    {NOTE_D5, QUARTER_NOTE}, {NOTE_E5, EIGHTH_NOTE}, {NOTE_F5, QUARTER_NOTE}, {NOTE_E5, EIGHTH_NOTE}, {NOTE_D5, QUARTER_NOTE}, {NOTE_C5, QUARTER_NOTE}, {NOTE_B4, QUARTER_NOTE}, {NOTE_G4, QUARTER_NOTE},
    {NOTE_A4, QUARTER_NOTE}, {NOTE_B4, QUARTER_NOTE}, {NOTE_C5, HALF_NOTE}, {NOTE_G5, QUARTER_NOTE}, {NOTE_F5, EIGHTH_NOTE}, {NOTE_E5, QUARTER_NOTE}, {NOTE_D5, EIGHTH_NOTE},
    {NOTE_C5, HALF_NOTE}, {NOTE_G5, QUARTER_NOTE}, {NOTE_F5, EIGHTH_NOTE}, {NOTE_E5, QUARTER_NOTE}, {NOTE_D5, EIGHTH_NOTE}, {NOTE_C5, HALF_NOTE}, {NOTE_REST, HALF_NOTE}
};
int deck_the_halls_length = sizeof(deck_the_halls_melody) / sizeof(Note);


// --- Helper Functions (no changes here) ---
void variable_delay_us(uint16_t us) {
    for (uint16_t i = 0; i < us; ++i) {
        __asm__ __volatile__ ("nop");
        __asm__ __volatile__ ("nop");
        __asm__ __volatile__ ("nop");
    }
}

void variable_delay_ms(uint16_t ms) {
    for (uint16_t i = 0; i < ms; ++i) {
        variable_delay_us(1000);
    }
}

void play_tone(uint16_t frequency, uint16_t duration_ms) {
    if (frequency == 0) {
        variable_delay_ms(duration_ms);
        return;
    }
    uint32_t period_us = 1000000UL / frequency;
    uint32_t half_period_us = period_us / 2;
    uint32_t total_cycles = (uint32_t)duration_ms * 1000 / period_us;

    for (uint32_t i = 0; i < total_cycles; ++i) {
        PORTB |= (1 << SPEAKER_PIN);
        variable_delay_us(half_period_us);
        PORTB &= ~(1 << SPEAKER_PIN);
        variable_delay_us(half_period_us);
    }
}


int main(void) {
    DDRB |= (1 << SPEAKER_PIN);

    while (1) {
        // --- Play Song 1: Jingle Bells ---
        for (int i = 0; i < jingle_bells_length; i++) {
            Note current_note = jingle_bells_melody[i];
            play_tone(current_note.frequency, current_note.duration);
            variable_delay_ms(50); // Short pause between notes
        }
        
        // --- Pause between songs ---
        variable_delay_ms(2000); 

        // --- Play Song 2: We Wish You a Merry Christmas ---
        for (int i = 0; i < we_wish_you_length; i++) {
            Note current_note = we_wish_you_melody[i];
            play_tone(current_note.frequency, current_note.duration);
            variable_delay_ms(50); // Short pause between notes
        }

        // --- Pause between songs ---
        variable_delay_ms(2000);

        // --- NEW: Play Song 3: Deck the Halls ---
        for (int i = 0; i < deck_the_halls_length; i++) {
            Note current_note = deck_the_halls_melody[i];
            play_tone(current_note.frequency, current_note.duration);
            variable_delay_ms(50); // Short pause between notes
        }

        // --- Pause before repeating the whole playlist ---
        variable_delay_ms(3000); 
    }
    return 0;
}

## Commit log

2026-04-19 Add C firmware: tactile switch and touch pad variants
    ATtiny85 V-USB HID keyboard firmware implementing the two-piece
    password split concept. Two variants:
    - tactile_switch: active-low push button on PB1, internal pull-up
    - touch_pad: TTP223 capacitive sensor on PB1, active-high
    Both use V-USB for USB HID keyboard enumeration at 16 MHz.
    Flash usage: ~22% of 8 KB (1.86 KB). Also includes the
    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
    [.step, KicadHardwareKey.step, QFN.kicad_pcb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]
2026-04-19 Add KiCad PCB designs: DIP, SOIC, QFN, QFN+TTP223 touch
    Four hardware variants in KiCad 7:
    - Through-Hole DIP: hand-solderable, prototyping friendly
    - SMD SOIC-8: compact, hand-solderable
    - SMD QFN-20: minimal footprint, tactile switch
    - SMD QFN-20 + TTP223: capacitive touch, 4-layer PCB for
    improved signal integrity
    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
